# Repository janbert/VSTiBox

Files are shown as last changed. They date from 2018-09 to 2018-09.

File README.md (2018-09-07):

# VSTiBox
VSTiBox is a dedicated VST host synth for live performance. It is a Windows based machine that contains all components to run VST software synths that are controlled by an external midi keyboard. Key components are:
- Micro-ATX with Intel i5 running Windows 7
- Custom wooden/acrylic lasercut case
- Custon VST host software written in C#
- Custom audio mixer with multiple I/O and headphone out
- Custom linear audio PSU 230Vac in, +/-10Vdc out
- Custom interface boards with 8x 24PPR encoders and 8x RGB silicon pad buttons 

See my project page at hackaday for more info: https://hackaday.io/project/160858-vstibox

# Build instructions
For all hardware v1.0 is added including the GERBER files that I used for ordering the pcb's. Both the mixer and the control interface contain bugs and need some rewiring. I have corrected the schematics in v1.1, but did not take the time to finish the pcb's. I do recommend finalizing the v1.1 boards if you want to build your own, instead of re-ordering my v1.0 versions. 

# Libraries
This project uses a number of libraries. 
- BlueWave.Interop.Asio	https://www.codeproject.com/Articles/24536/Low-Latency-Audio-using-ASIO-Drivers-in-NET?msg=4526889
- VST.NET               https://github.com/obiwanjacobi/vst.net
- midi-dot-net	        https://code.google.com/archive/p/midi-dot-net/
- DirectMidi.net        http://directmidinet.sourceforge.net/
- NAudio	              https://github.com/naudio/NAudio
- OpenHardwareMonitor	  https://openhardwaremonitor.org
- PDFViewer	            https://www.codeproject.com/Articles/37458/PDF-Viewer-Control-Without-Acrobat-Reader-Installe

# License
This project is distributed under the the GNU general public license v3.

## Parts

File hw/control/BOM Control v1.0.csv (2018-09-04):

Qty | Value | Device | Package | Parts | Description
2 |  | M04LOCK | 1X04_LOCK | JP2, JP6 | Header 4
1 |  | PINHD-1X3 | 1X03 | JP1 | PIN HEADER
12 | 100 | R-EU_R0603 | R0603 | R4, R7, R8, R10, R12, R15, R16, R17, R18, R19, R22, R23 | RESISTOR, European symbol
3 | 100nF | C-EUC0603 | C0603 | C3, C14, C15 | CAPACITOR, European symbol
1 | 100nF | CAP0603-CAP | 0603-CAP | C2 | Capacitor
2 | 100uF 6.3V | CPOL-EUSMCB | SMC_B | C1, C4 | POLARIZED CAPACITOR, European symbol
1 | 10MHz | CRYSTALSMD | HC49UP | Y1 | Various standard crystals. Proven footprints. Spark Fun Electronics SKU : COM-00534
5 | 10k | R-EU_R0603 | R0603 | R3, R13, R14, R20, R21 | RESISTOR, European symbol
2 | 10k lin | TRIM_EU-3223W | 3223W | R28, R29 | POTENTIOMETER
4 | 150 | R-EU_R0603 | R0603 | R1, R6, R26, R33 | RESISTOR, European symbol
2 | 20pF | C-EUC0603 | C0603 | C5, C6 | CAPACITOR, European symbol
4 | 348 | R-EU_R0603 | R0603 | R5, R25, R32, R35 | RESISTOR, European symbol
2 | 4k7 | R-EU_R0603 | R0603 | R30, R31 | RESISTOR, European symbol
4 | 620 | R-EU_R0603 | R0603 | R2, R24, R27, R34 | RESISTOR, European symbol
2 | BUTTONPAD-2X1 | BUTTONPAD-2X1 | BUTTONPAD-2X1 | U$1, U$3
1 | ENC1 | M04PTH | 1X04 | JP4 | Header 4
1 | ENC2 | M04PTH | 1X04 | JP5 | Header 4
1 | ENC3 | M04PTH | 1X04 | JP7 | Header 4
1 | ENC4 | M04PTH | 1X04 | JP8 | Header 4
1 | JTAG_10WAY | JTAG_10WAY | JTAG_10WAY_1.27MM | X1
1 | LM1117_3V3 | LM1117_3V3 | SOT223 | U$26
1 | LPC1113/14-LQFP48 | LPC1113/14-LQFP48 | LQFP48 | U$4 | NXP Semiconductors
1 | M02PTH | M02PTH | 1X02 | JP9 | Standard 2-pin 0.1 header. Use with"
1 | OPA177S | OPA177S | SO08 | IC1 | Precision Operational Amplifier
12 | PMV31XN | MOSFET-NREFLOW | SOT23 | Q3, Q4, Q5, Q6, Q7, Q8, Q9, Q10, Q11, Q12, Q13, Q14 | N-Channel Mosfet
1 | SE95DP | SE95DP | TSSOP8-SOT505-1 | U2

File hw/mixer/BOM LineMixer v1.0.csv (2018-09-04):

Qty | Value | Device | Package | Parts | Description
4 |  | NSJ12HF-1 | NSJ12HF-1 | U$1, U$2, U$3, U$6 | Stereo dual jack, full threaded nose
1 | 1.62M | R-EU_R0603 | R0603 | R49 | RESISTOR, European symbol
8 | 100R | R-EU_0207/7 | 0207/7 | R29, R30, R31, R32, R61, R62, R63, R64 | RESISTOR, European symbol
8 | 100k | R-EU_0207/7 | 0207/7 | R1, R2, R3, R4, R10, R27, R45, R46 | RESISTOR, European symbol
1 | 100k\ | R-EU_0207/7 | 0207/7 | R11 | RESISTOR, European symbol
20 | 100n | C-EUC0603 | C0603 | C1, C2, C3, C4, C5, C6, C20, C21, C22, C23, C24, C25, C39, C41, C44, C46, C47, C48, C49, C50 | CAPACITOR, European symbol
2 | 100nF | C-EUC0603 | C0603 | C28, C29 | CAPACITOR, European symbol
6 | 10k | R-EU_0207/7 | 0207/7 | R13, R14, R18, R19, R28, R35 | RESISTOR, European symbol
3 | 10k log | 3RP/1610G | 3RP/1610G | R9, R22, R44 | 16mm Potentiometer two level
2 | 10nF | C-EUC0603 | C0603 | C33, C34 | CAPACITOR, European symbol
4 | 1M | R-EU_0207/7 | 0207/7 | R51, R52, R56, R58 | RESISTOR, European symbol
6 | 1k | R-EU_0207/7 | 0207/7 | R53, R54, R55, R57, R59, R60 | RESISTOR, European symbol
2 | 1uF | C-EUC0603 | C0603 | C30, C38 | CAPACITOR, European symbol
1 | 1uf | C-EUC0603 | C0603 | C37 | CAPACITOR, European symbol
1 | 20k8 | R-EU_R0603 | R0603 | R47 | RESISTOR, European symbol
1 | 215k | R-EU_R0603 | R0603 | R50 | RESISTOR, European symbol
7 | 220p | C-EUC0603K | C0603K | C12, C13, C14, C17, C18, C31, C32 | CAPACITOR, European symbol
2 | 220uF | CPOL-EUD/7343-31R | D/7343-31R | C35, C36 | POLARIZED CAPACITOR, European symbol
22 | 2k49 | R-EU_0207/7 | 0207/7 | R5, R6, R7, R8, R12, R17, R20, R21, R23, R24, R25, R26, R33, R34, R36, R37, R38, R39, R40, R41, R42, R43 | RESISTOR, European symbol
1 | 2k87 | R-EU_R0603 | R0603 | R48 | RESISTOR, European symbol
5 | 4.7uF | C15/7 | C15B7 | C7, C8, C9, C10, C11 | CAPACITOR
3 | 47p | C-EUC0603K | C0603K | C15, C16, C19 | CAPACITOR, European symbol
2 | 47uF | CPOL-EUD/7343-31R | D/7343-31R | C26, C27 | POLARIZED CAPACITOR, European symbol
2 | 4k99 | R-EU_0207/7 | 0207/7 | R15, R16 | RESISTOR, European symbol
4 | 4u7 16V | C-EUC1206 | C1206 | C40, C42, C43, C45 | CAPACITOR, European symbol
4 | DRV134SO-8 | DRV134SO-8 | SO-8 | U1, U2, U3, U4
1 | INA2134-EP | INA2134U | SO14 | IC1 | Audio Differential Line Receivers
2 | LM4558D | LM4558D | SO08 | IC2, IC5 | OP AMP
1 | LM4562 | LM4558D | SO08 | IC4 | OP AMP
2 | LME49600 | LME49600 | TS5B | IC7, IC8 | High Performance, High Fidelity, High Current Audio Buffer
2 | LME49740 | TL074D | SO14 | IC3, IC6 | OP AMP
3 | MOUNT-HOLE3.2 | MOUNT-HOLE3.2 | 3,2 | H1, H3, H4 | MOUNTING HOLE with drill center marker
15 | PAD1.5MM | PAD1.5MM | PAD_1.5MM | U$7, U$8, U$10, U$11, U$12, U$13, U$14, U$15, U$16, U$17, U$18, U$19, U$20, U$21, U$22
5 | SOLDERLINK | SOLDERLINK | SOLDERLINK | S1, S2, S3, S4, S5
1 | TPS7A3301KC | TPS7A3301KC | TO220-7 | U$4 | Ultralow-Noise Negative Voltage Regulator v3
1 | TPS7A4501 | TPS7A4501 | SOT223-5 | U$5 | LOW-NOISE FAST-TRANSIENT-RESPONSE 1.5-A LOW-DROPOUT VOLTAGE

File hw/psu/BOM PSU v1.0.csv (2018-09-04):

Qty | Value | Device | Package | Parts | Description
7 | Schottky MBR0520L | DIODE-DO214AC | DO214AC | D1, D2, D3, D4, D5, D6, D7, D8 | DIODE
2 | 1 | R-EU_R0603 | R0603 | R2, R3 | RESISTOR, European symbol
4 | 10uF 25V 0805 | C-EUC1206 | C1206 | C11, C12, C27, C28 | CAPACITOR, European symbol
1 | 1MEG | R-EU_0309/12 | 0309/12 | R6 | RESISTOR, European symbol
2 | 1nF | C-EUC0603 | C0603 | C31, C32 | CAPACITOR, European symbol
2 | 1uF | C-EUC0603 | C0603 | C17, C18 | CAPACITOR, European symbol
2 | 3300uF 25V | CPOL-EUE7.5-16 | E7,5-16 | C23, C24 | POLARIZED CAPACITOR, European symbol
2 | 4700uF 16V | CPOL-EUE7.5-16 | E7,5-16 | C9, C10 | POLARIZED CAPACITOR, European symbol
2 | 47uF 16V 1210 | C-EUC1210 | C1210 | C25, C26 | CAPACITOR, European symbol
3 | S10K300 | S10K300 | S10K300 | R1, R4, R5 | VARISTOR
1 | Talema 70022K 5VA 2x12Vac | TALEMA_70000 | TALEMA_70000 | L2 | TRANSFORMER
1 | Hammond 1591XXSSFLBK |  |  |  | ABS Enclosure, IP54, Flanged, 112.52 x 84.62 x 41.25mm
1 | FIX-GR-1 |  |  |  | Rubber grommet
2 | FIX-GR-30 |  |  |  | Rubber grommet
2 | TPS7A4700 | TPS7A4700 | VQFN20 | U1, U2 | Ultralow-noise LDO
1 | TAKAMISAWA NA12W-K
1 | SU9V-R01180 | SU9V-R01180 | SU9V-R01180 | L1 | Common mode choke
2 | KF301-3P | MKDSN1,5/3-5,08 | MKDSN1,5/3-5,08 | X1, X2 | MKDSN 1,5/ 3-5,08 Printklemme
1 | KF301-2P
1 | 47nF 600V 473J | C-EU102-064X133 | C102-064X133 | C19 | CAPACITOR, European symbol
2 | 4.7nF Class Y VY1472M61Y5UC63V0 | C-EU102-054X133 | C102-054X133 | C21, C22 | CAPACITOR, European symbol
1 | 100nF 400V 104J | C-EU150-064X183 | C150-064X183 | C20 | CAPACITOR, European symbol
1 | FUSEX20MM | FUSEX20MM | FUSE_5MM | F1
14 | 100nF : type MLCC?! | C-EUC0603 | C0603 | C1, C2, C3, C4, C5, C6, C7, C8, C13, C14, C15, C16, C29, C30 | CAPACITOR, European symbol

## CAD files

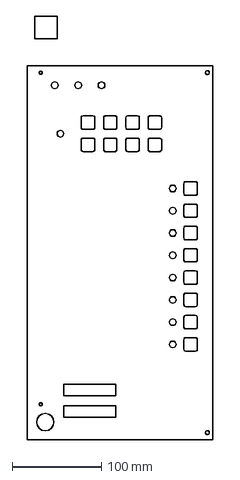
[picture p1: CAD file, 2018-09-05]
cad/lasercut/1_16 inch/Topplate clear.DXF
207.9 x 475.5 mm

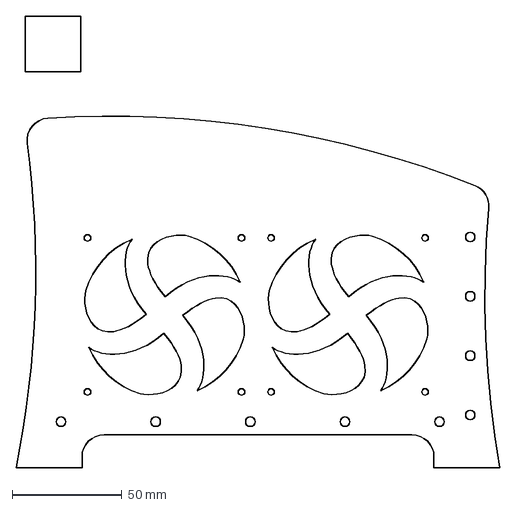
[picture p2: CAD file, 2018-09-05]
cad/lasercut/1_2 inch/Sideplate fanholes clear 1_2inch.DXF
220.0 x 205.4 mm

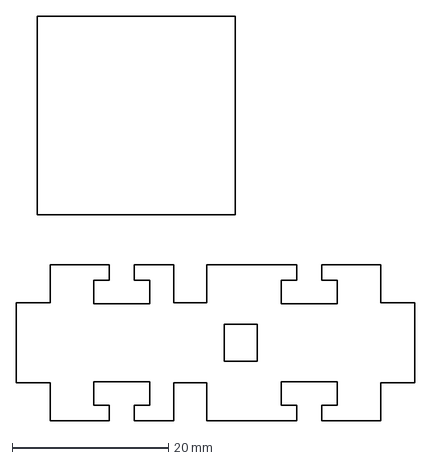
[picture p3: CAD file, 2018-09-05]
cad/lasercut/3_16 inch/Modwheel side.DXF
51.0 x 51.8 mm

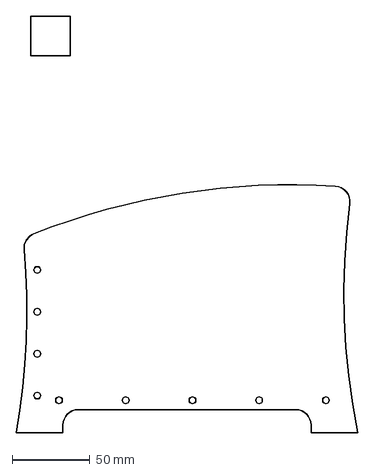
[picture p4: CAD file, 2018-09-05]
cad/lasercut/1_2 inch/Sideplate no fanholes clear 1_2inch.DXF
220.0 x 268.5 mm

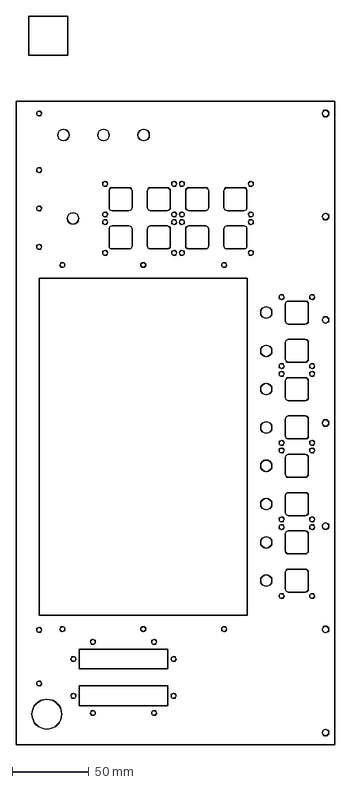
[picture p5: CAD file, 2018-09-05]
cad/lasercut/3_16 inch/Topplate black.DXF
207.9 x 475.5 mm

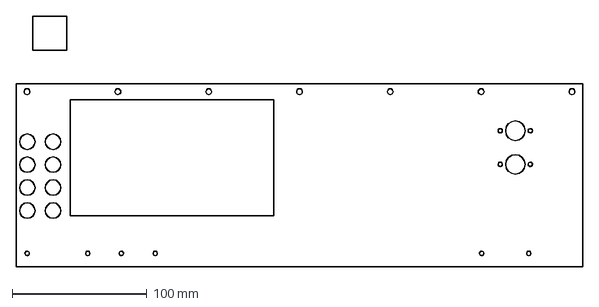
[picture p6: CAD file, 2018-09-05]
cad/lasercut/3_16 inch/Back plate.DXF
420.0 x 186.1 mm

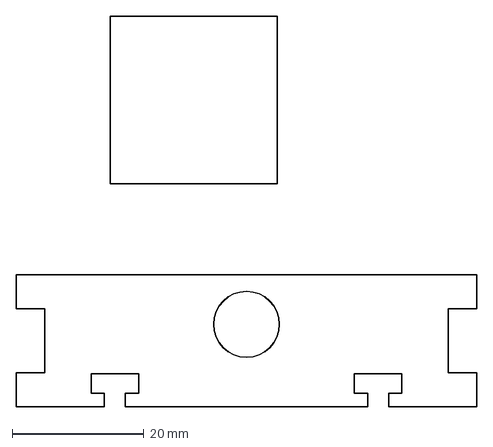
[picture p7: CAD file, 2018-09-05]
cad/lasercut/3_16 inch/Modwheel base.DXF
70.0 x 59.3 mm

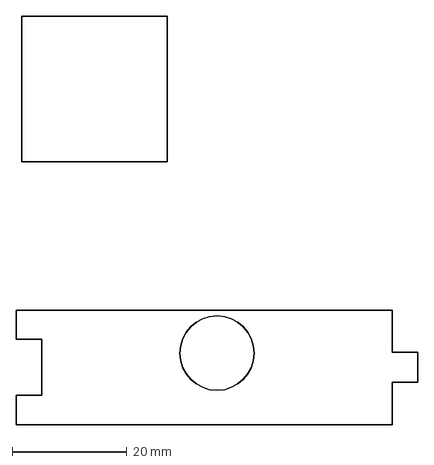
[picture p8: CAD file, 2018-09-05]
cad/lasercut/3_16 inch/Modwheel mid.DXF
70.0 x 71.3 mm

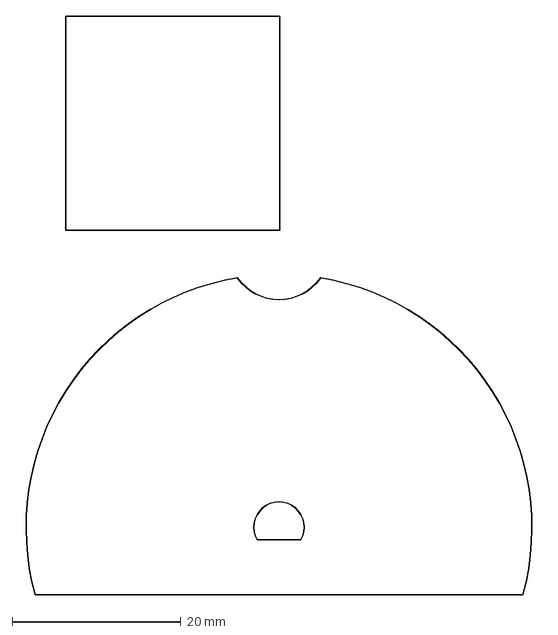
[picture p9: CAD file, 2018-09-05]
cad/lasercut/3_16 inch/Modwheel.DXF
62.4 x 68.6 mm

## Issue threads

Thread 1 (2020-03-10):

Great work!

beevabeeva, 2020-03-10:
Hi there Jan!

I am so glad I found your project.
I've wanted to create a similar thing for years.
Your software setup looks great!
I'd want to add a patch browser (with giant text so I can see the patch name while playing live) - Similar to something like Apples' Mainstage.

I am not going for something as elaborate in terms of the custom controller hardware (which is very cool!).

This is my plan:

Casio CDP 100
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

# +
Korg Nano Kontrol
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

# +

Mini pc with serial port for midi in (creating a midi to serial connector will be faster than any midi to usb converter unfortunately. For newer keyboards with usb to usb, this is not an issue).
i5 or i7 with as much RAM possible. +- 128 GB SSD.
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

# +

10 or 13 inch touch screen monitor.
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

I want to build a road case for the keyboard and have everything fit into that.
Something like this:
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

Finally, I'll have a plug bar in the case, so that I can leave everything plugged in and connected. I'll only need to plug one thing in and be ready to play. Like the good old days.

Thanks for sharing your work. It will definitely help me.

janbert, 2020-03-10:
Hi, nice to see that my project inspired you! Nice to see your plans too. Good luck building it! I'm curious to see the result so please send me a pic once you have finished it.
Regards, Jan Bert

________________________________
Van: beevabeeva <notifications@github.com>
Verzonden: dinsdag 10 maart 2020 03:43
Aan: janbert/VSTiBox <VSTiBox@noreply.github.com>
CC: Subscribed <subscribed@noreply.github.com>
Onderwerp: [janbert/VSTiBox] Great work! (#1)

Hi there Jan!

I am so glad I found your project.
I've wanted to create a similar thing for years.
Your software setup looks great!
I'd want to add a patch browser (with giant text so I can see the patch name while playing live) - Similar to something like Apples' Mainstage.

I am not going for something as elaborate in terms of the custom controller hardware (which is very cool!).

This is my plan:

Casio CDP 100
[Casio CDP100]<https://user-images.githubusercontent.com/19332617/76275354-baab8300-628b-11ea-8126-89058b77c8d9.png>

+

Korg Nano Kontrol
[image]<https://user-images.githubusercontent.com/19332617/76275462-0f4efe00-628c-11ea-92bd-5e58f79c2b51.png>

+

Mini pc with serial port for midi in (creating a midi to serial connector will be faster than any midi to usb converter unfortunately. For newer keyboards with usb to usb, this is not an issue).
i5 or i7 with as much RAM possible. +- 128 GB SSD.
[image]<https://user-images.githubusercontent.com/19332617/76275889-1fb3a880-628d-11ea-8df0-2ead58ff0844.png>

+

10 or 13 inch touch screen monitor.
[image]<https://user-images.githubusercontent.com/19332617/76276186-de6fc880-628d-11ea-93c6-8c37bda4e486.png>

I want to build a road case for the keyboard and have everything fit into that.
Something like this:
[image]<https://user-images.githubusercontent.com/19332617/76276365-4a523100-628e-11ea-9f9d-8cefc426486c.png>

Finally, I'll have a plug bar in the case, so that I can leave everything plugged in and connected. I'll only need to plug one thing in and be ready to play. Like the good old days.

Thanks for sharing your work. It will definitely help me.

—
You are receiving this because you are subscribed to this thread.
Reply to this email directly, view it on GitHub<https://github.com/janbert/VSTiBox/issues/1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>, or unsubscribe<https://github.com/notifications/unsubscribe-auth/AB74PQ2VKLS2KZMVR3TWKJLRGWZNLANCNFSM4LEWGVQA>.

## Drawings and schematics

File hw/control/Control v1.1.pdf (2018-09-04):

POWER | TEMPERATURE SENSOR

# SWD

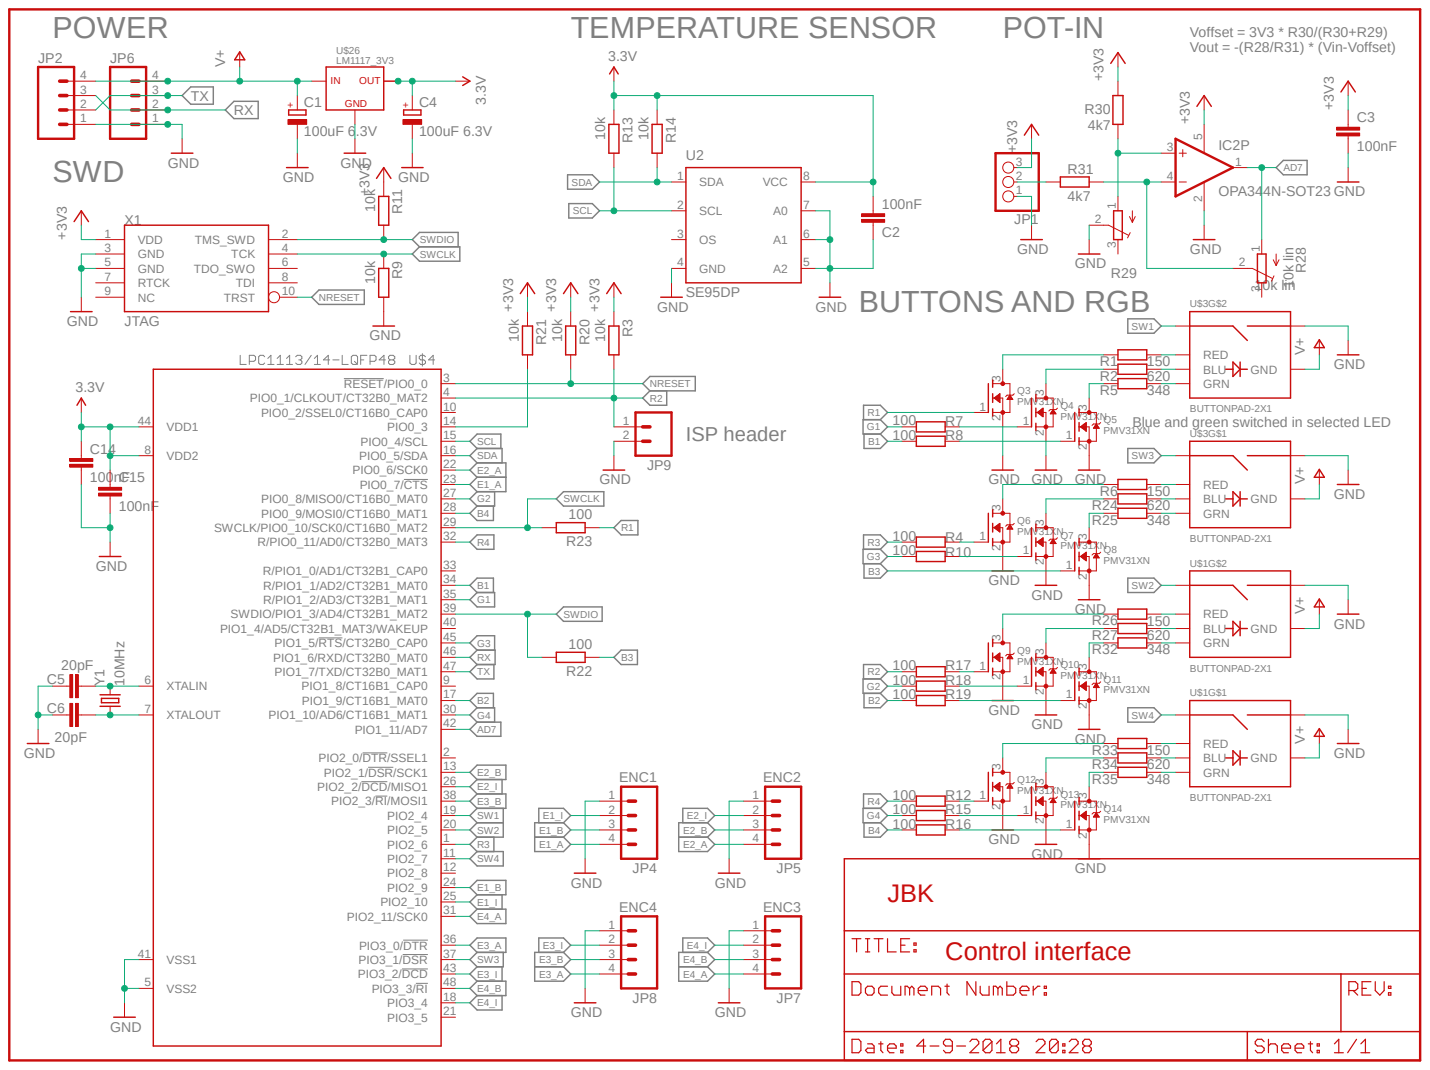
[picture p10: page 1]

Blue and green switched in selected LED

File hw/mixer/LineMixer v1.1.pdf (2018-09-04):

2k49 | 100k
GND | 4u7 16V 4u7 16V | 4u7 16V ⁴u7 16V

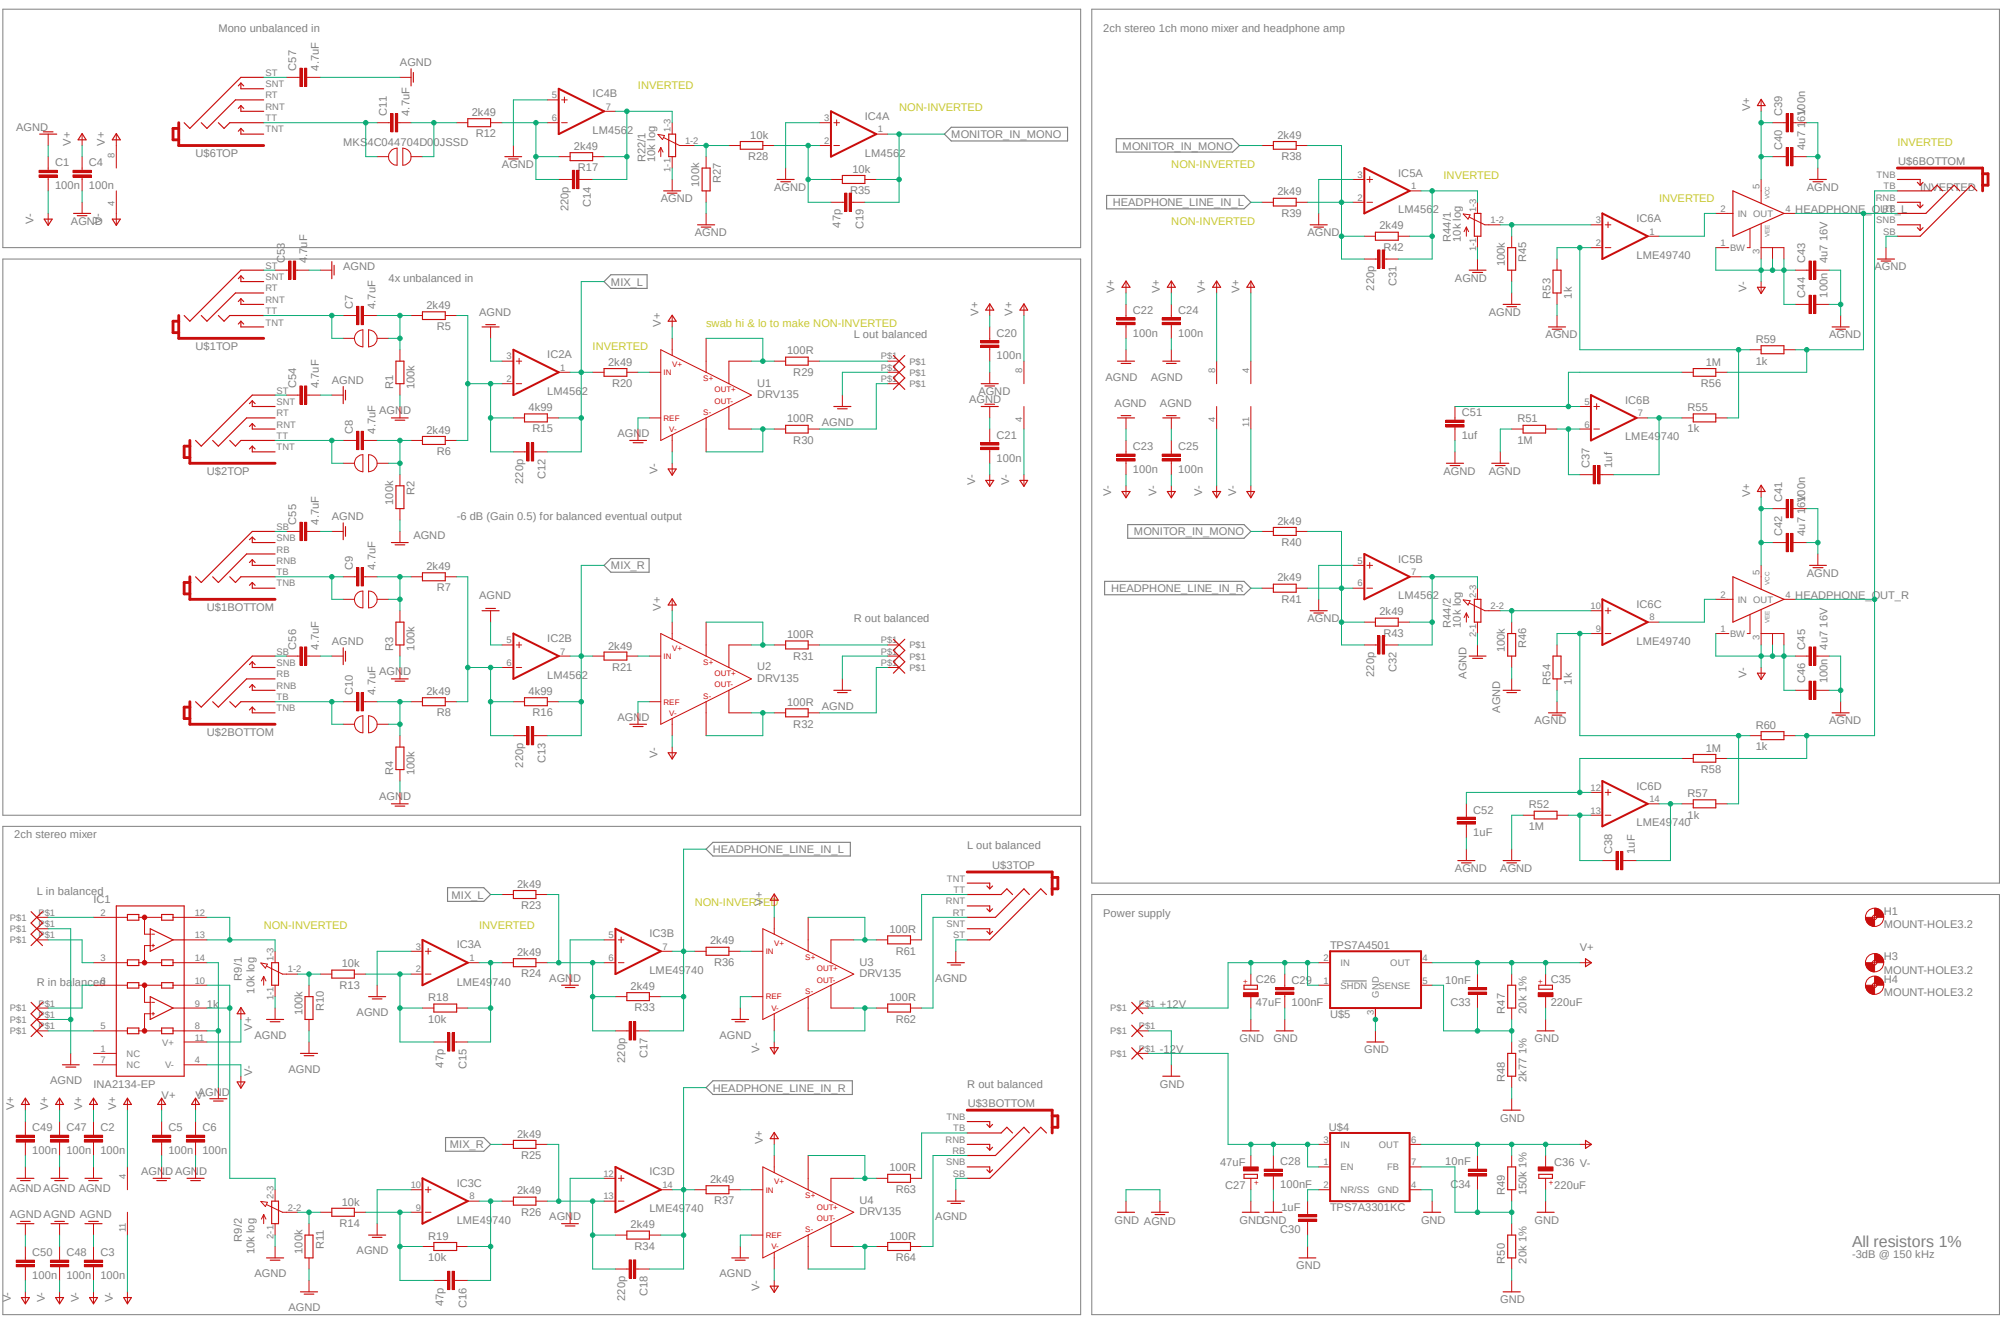
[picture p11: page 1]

2ch stereo 1ch mono mixer and headphone amp

C33 C¹¹ C⁷ C⁸ C⁹ C¹⁰

swab hi & lo to make NON-INVERTED

-6 dB (Gain 0.5) for balanced eventual output

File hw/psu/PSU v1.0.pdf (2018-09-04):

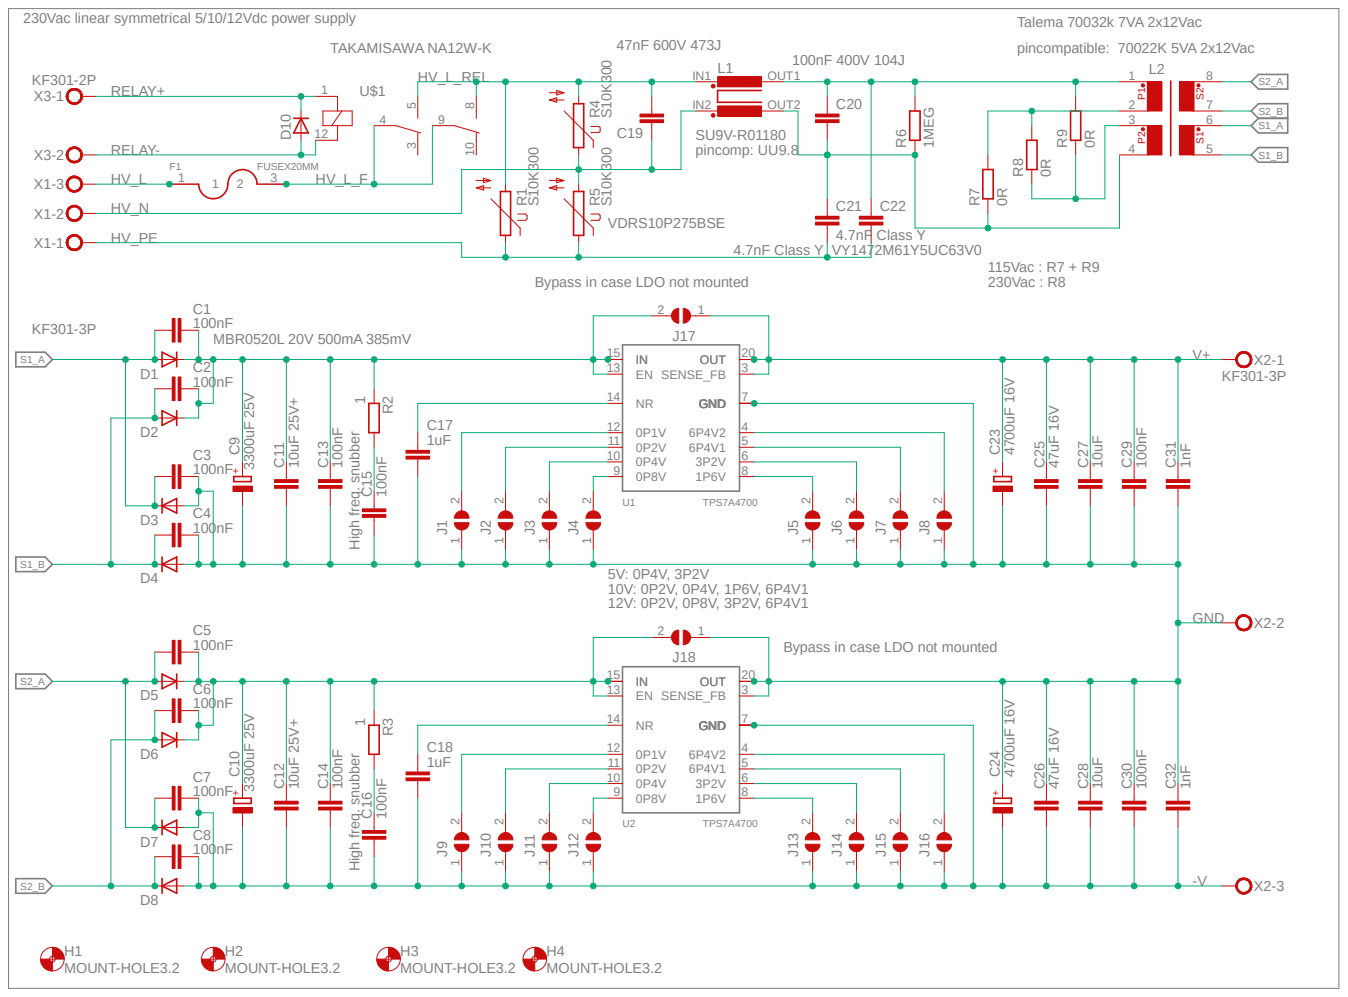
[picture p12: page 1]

230Vac linear symmetrical 5/10/12Vdc power supply

Bypass in case LDO not mounted

Bypass in case LDO not mounted High freq. snubber High freq. snubber

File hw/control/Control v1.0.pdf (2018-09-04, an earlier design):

POWER | TEMPERATURE SENSOR

# SWD

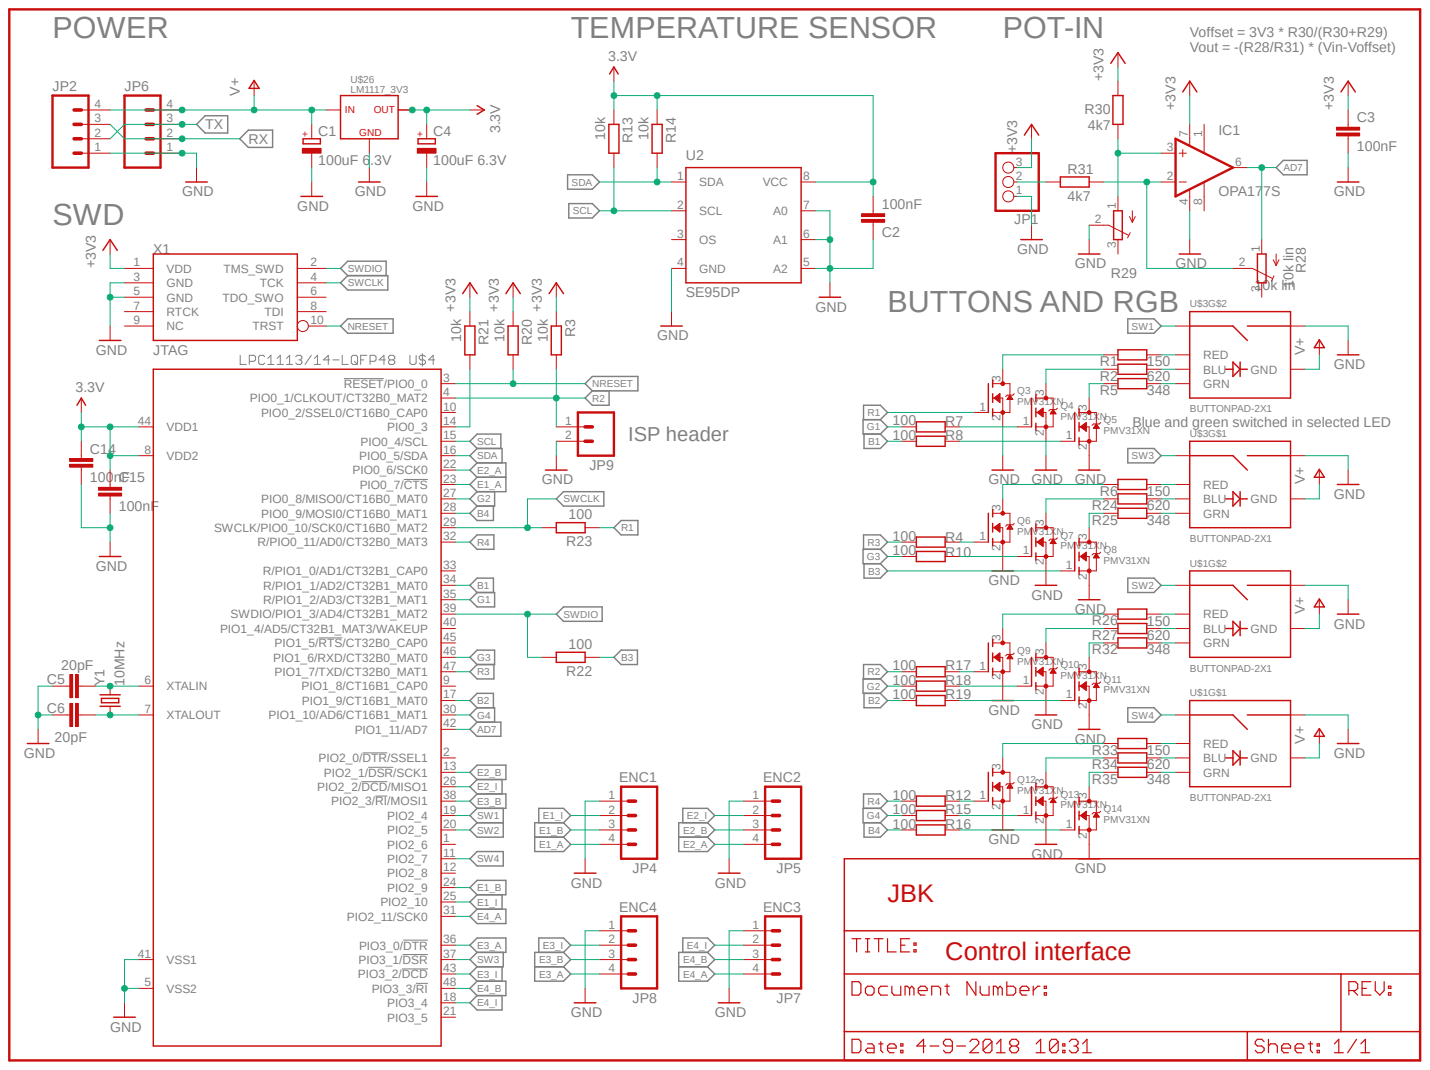
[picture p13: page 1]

Blue and green switched in selected LED

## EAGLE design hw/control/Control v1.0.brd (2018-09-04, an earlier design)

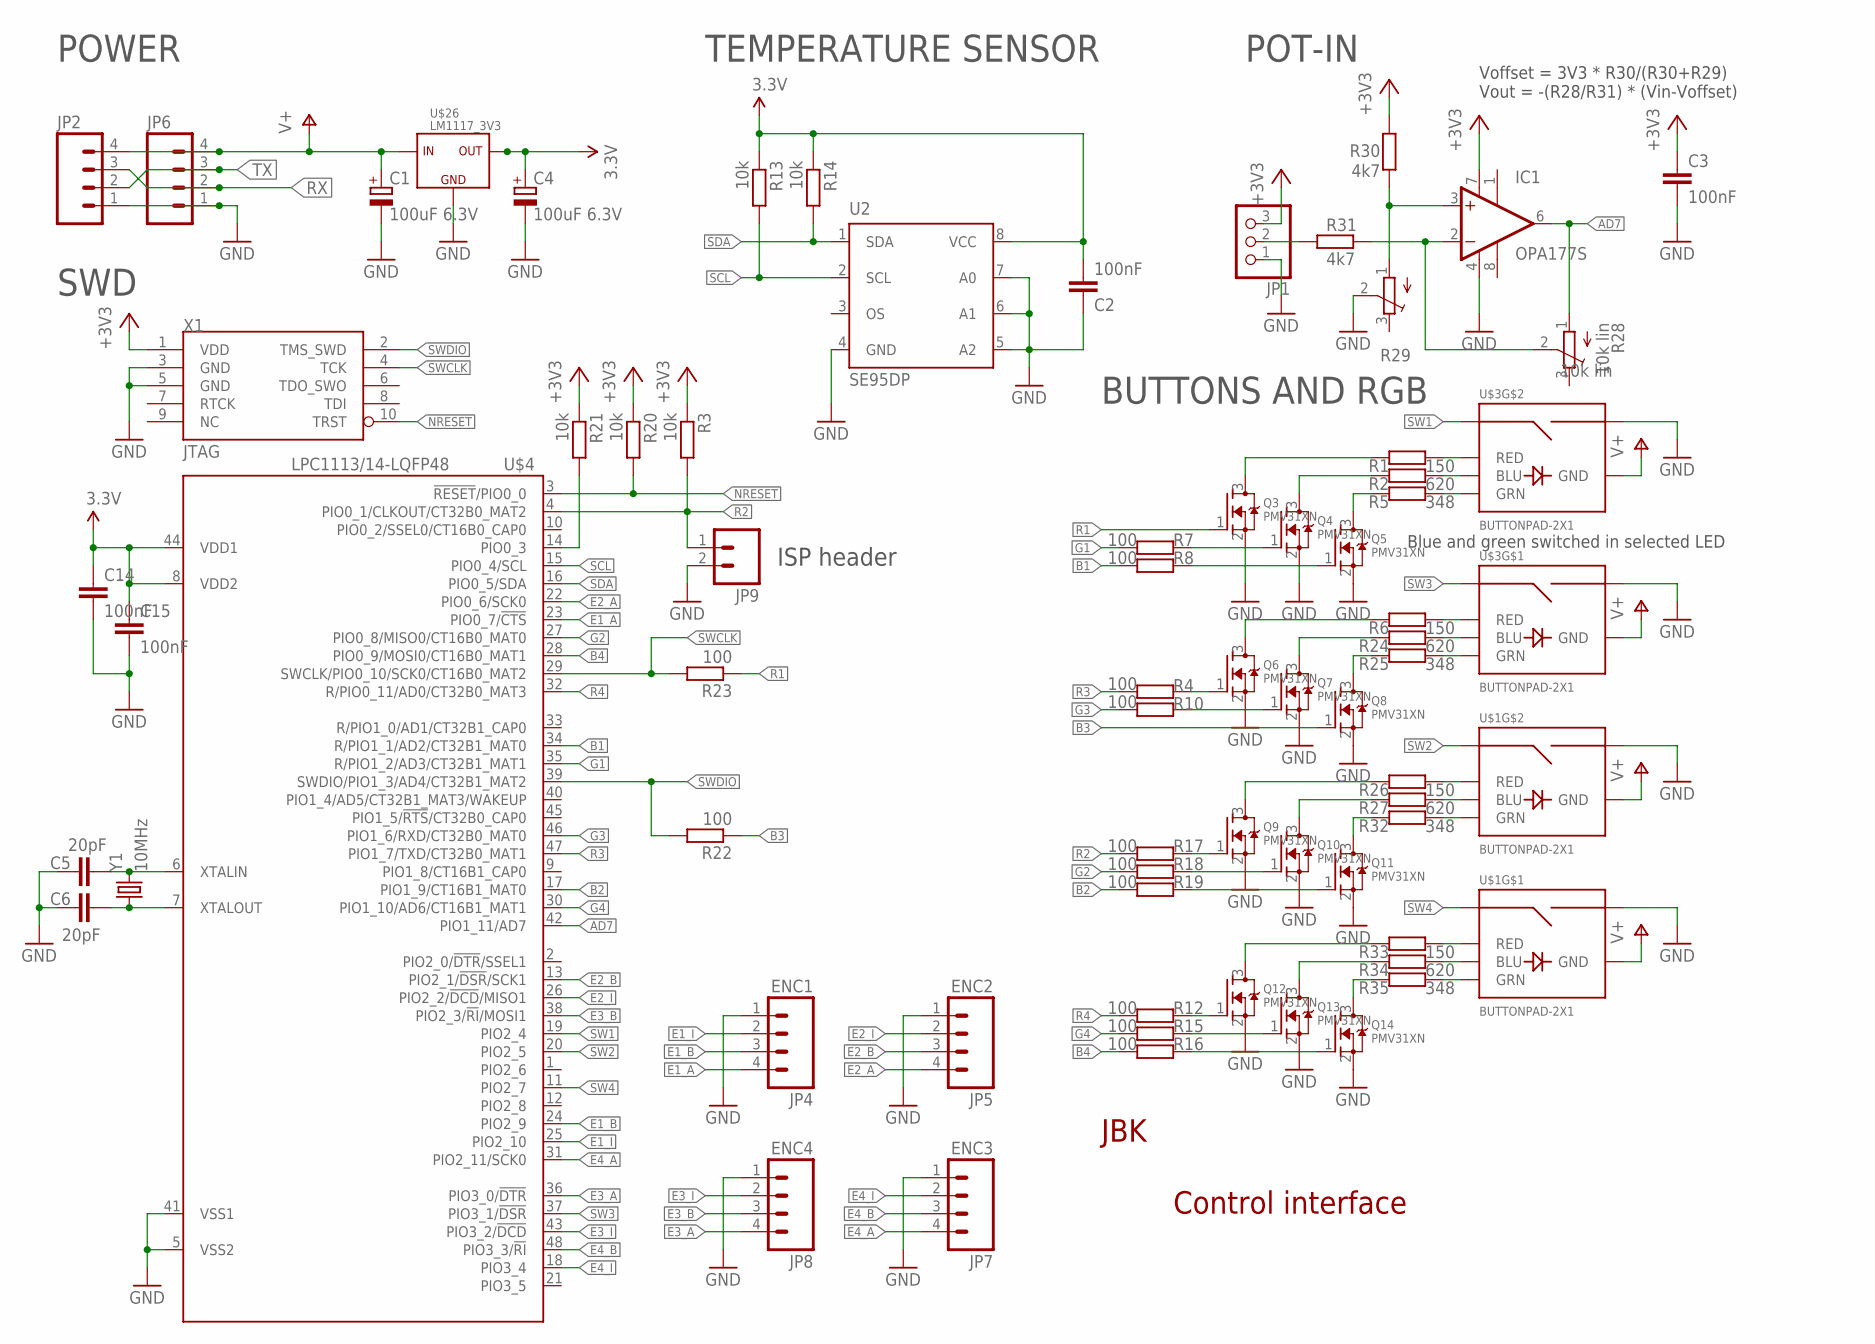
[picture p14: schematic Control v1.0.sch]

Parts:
C1, C4: 100uF 6.3V; SMC_B
C2: 100nF; 0603-CAP
C3, C14, C15: 100nF; C0603
C5, C6: 20pF; C0603
IC1: OPA177S; SO08
JP1: PINHD-1X3; 1X03
JP2, JP6: M04LOCK; 1X04_LOCK
JP4: ENC1; 1X04
JP5: ENC2; 1X04
JP7: ENC3; 1X04
JP8: ENC4; 1X04
JP9: M02PTH; 1X02
Q3, Q4, Q5, Q6, Q7, Q8, Q9, Q10, Q11, Q12, Q13, Q14: PMV31XN; SOT23
R1, R6, R26, R33: 150; R0603
R2, R24, R27, R34: 620; R0603
R3, R13, R14, R20, R21: 10k; R0603
R4, R7, R8, R10, R12, R15, R16, R17, R18, R19, R22, R23: 100; R0603
R5, R25, R32, R35: 348; R0603
R28, R29: 10k lin; 3223W
R30, R31: 4k7; R0603
U2: SE95DP; TSSOP8-SOT505-1
U$1, U$3: BUTTONPAD-2X1
U$4: LPC1113/14-LQFP48; LQFP48
U$26: LM1117_3V3; SOT223
X1: JTAG_10WAY; JTAG_10WAY_1.27MM
Y1: 10MHz; HC49UP

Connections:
+3V3: C2.2, C3.1, C4.+, C14.1, C15.1, IC1.7 (V+), JP1.3, R3.1, R13.1, R14.1, R20.1, R21.1, R30.2, U2.8 (VCC), U$4.8 (VDD2), U$4.44 (VDD1), U$26.2 (OUT), U$26.4 (OUT), X1.1 (VDD)
AD7: IC1.6 (OUT), R28.1 (A), U$4.42 (PIO1_11/AD7)
B1: R8.2, U$4.34 (R/PIO1_1/AD2/CT32B1_MAT0)
B2: R19.2, U$4.17 (PIO1_9/CT16B1_MAT0)
B3: Q8.1 (G), R22.1
B4: R16.2, U$4.28 (PIO0_9/MOSI0/CT16B0_MAT1)
E1_A: JP4.4, U$4.23 (PIO0_7/!CTS!)
E1_B: JP4.3, U$4.24 (PIO2_9)
E1_I: JP4.2, U$4.25 (PIO2_10)
E2_A: JP5.4, U$4.22 (PIO0_6/SCK0)
E2_B: JP5.3, U$4.13 (PIO2_1/!DSR!/SCK1)
E2_I: JP5.2, U$4.26 (PIO2_2/!DCD!/MISO1)
E3_A: JP8.4, U$4.36 (PIO3_0/!DTR!)
E3_B: JP8.3, U$4.38 (PIO2_3/!RI!/MOSI1)
E3_I: JP8.2, U$4.43 (PIO3_2/!DCD!)
E4_A: JP7.4, U$4.31 (PIO2_11/SCK0)
E4_B: JP7.3, U$4.48 (PIO3_3/!RI!)
E4_I: JP7.2, U$4.18 (PIO3_4)
G1: R7.2, U$4.35 (R/PIO1_2/AD3/CT32B1_MAT1)
G2: R18.2, U$4.27 (PIO0_8/MISO0/CT16B0_MAT0)
G3: R10.2, U$4.46 (PIO1_6/RXD/CT32B0_MAT0)
G4: R15.2, U$4.30 (PIO1_10/AD6/CT16B1_MAT1)
GND: C1.-, C2.1, C3.2, C4.-, C5.1, C6.1, C14.2, C15.2, IC1.4 (V-), JP1.1, JP2.1, JP4.1, JP5.1, JP6.1, JP7.1, JP8.1, JP9.2, Q3.2 (S), Q4.2 (S), Q5.2 (S), Q6.2 (S), Q7.2 (S), Q8.2 (S), Q9.2 (S), Q10.2 (S), Q11.2 (S), Q12.2 (S), Q13.2 (S), Q14.2 (S), R29.2 (S), U2.4 (GND), U2.5 (A2), U2.6 (A1), U2.7 (A0), U$1.SW0-1 (SIG2), U$1.SW1-1 (SIG2), U$3.SW0-1 (SIG2), U$3.SW1-1 (SIG2), U$4.5 (VSS2), U$4.41 (VSS1), U$26.1, X1.3 (GND), X1.5 (GND)
unnamed: Q6.3 (D), R6.1
unnamed: Q7.3 (D), R24.1
unnamed: Q8.3 (D), R25.1
unnamed: R21.2, U$4.14 (PIO0_3)
unnamed: Q6.1 (G), R4.1
unnamed: Q4.3 (D), R2.1
unnamed: Q5.3 (D), R5.1
unnamed: IC1.2 (-IN), R28.2 (S), R31.2
unnamed: IC1.3 (+IN), R29.1 (A), R30.1
unnamed: Q7.1 (G), R10.1
unnamed: Q9.1 (G), R17.1
unnamed: Q9.3 (D), R26.1
unnamed: Q10.3 (D), R27.1
unnamed: Q3.3 (D), R1.1
unnamed: Q11.3 (D), R32.1
unnamed: Q4.1 (G), R7.1
unnamed: Q5.1 (G), R8.1
unnamed: Q10.1 (G), R18.1
unnamed: Q11.1 (G), R19.1
unnamed: JP1.2, R31.1
unnamed: C5.2, U$4.6 (XTALIN), Y1.2
unnamed: C6.2, U$4.7 (XTALOUT), Y1.1
unnamed: Q12.1 (G), R12.1
unnamed: Q12.3 (D), R33.1
unnamed: Q13.3 (D), R34.1
unnamed: Q14.3 (D), R35.1
unnamed: Q13.1 (G), R15.1
unnamed: Q14.1 (G), R16.1
unnamed: R1.2, U$3.RED1 (RED)
unnamed: R2.2, U$3.BLU1 (BLU)
unnamed: R5.2, U$3.GRN1 (GRN)
unnamed: R6.2, U$3.RED0 (RED)
unnamed: R24.2, U$3.BLU0 (BLU)
unnamed: R25.2, U$3.GRN0 (GRN)
unnamed: R26.2, U$1.RED1 (RED)
unnamed: R27.2, U$1.BLU1 (BLU)
unnamed: R32.2, U$1.GRN1 (GRN)
unnamed: R33.2, U$1.RED0 (RED)
unnamed: R34.2, U$1.BLU0 (BLU)
unnamed: R35.2, U$1.GRN0 (GRN)
NRESET: R20.2, U$4.3 (!RESET!/PIO0_0), X1.10 (TRST)
R1: Q3.1 (G), R23.1
R2: JP9.1, R3.2, R17.2, U$4.4 (PIO0_1/CLKOUT/CT32B0_MAT2)
R3: R4.2, U$4.47 (PIO1_7/TXD/CT32B0_MAT1)
R4: R12.2, U$4.32 (R/PIO0_11/AD0/CT32B0_MAT3)
RX: JP2.3, JP6.2
SCL: R13.2, U2.2 (SCL), U$4.15 (PIO0_4/SCL)
SDA: R14.2, U2.1 (SDA), U$4.16 (PIO0_5/SDA)
SW1: U$3.SW1-0 (SIG1), U$4.19 (PIO2_4)
SW2: U$1.SW1-0 (SIG1), U$4.20 (PIO2_5)
SW3: U$3.SW0-0 (SIG1), U$4.37 (PIO3_1/!DSR!)
SW4: U$1.SW0-0 (SIG1), U$4.11 (PIO2_7)
SWCLK: R23.2, U$4.29 (SWCLK/PIO0_10/SCK0/CT16B0_MAT2), X1.4 (TCK)
SWDIO: R22.2, U$4.39 (SWDIO/PIO1_3/AD4/CT32B1_MAT2), X1.2 (TMS_SWD)
TX: JP2.2, JP6.3
V+: C1.+, JP2.4, JP6.4, U$1.GND0 (GND), U$1.GND1 (GND), U$3.GND0 (GND), U$3.GND1 (GND), U$26.3

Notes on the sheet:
Control interface
JBK
TEMPERATURE SENSOR
POWER
SWD
ISP header
Voffset = 3V3 * R30/(R30+R29) Vout = -(R28/R31) * (Vin-Voffset)
POT-IN
BUTTONS AND RGB
Blue and green switched in selected LED

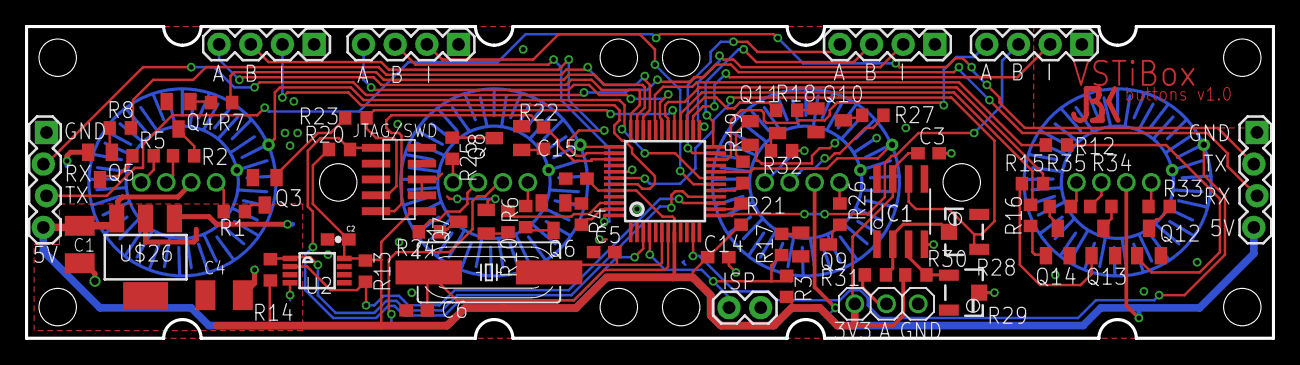
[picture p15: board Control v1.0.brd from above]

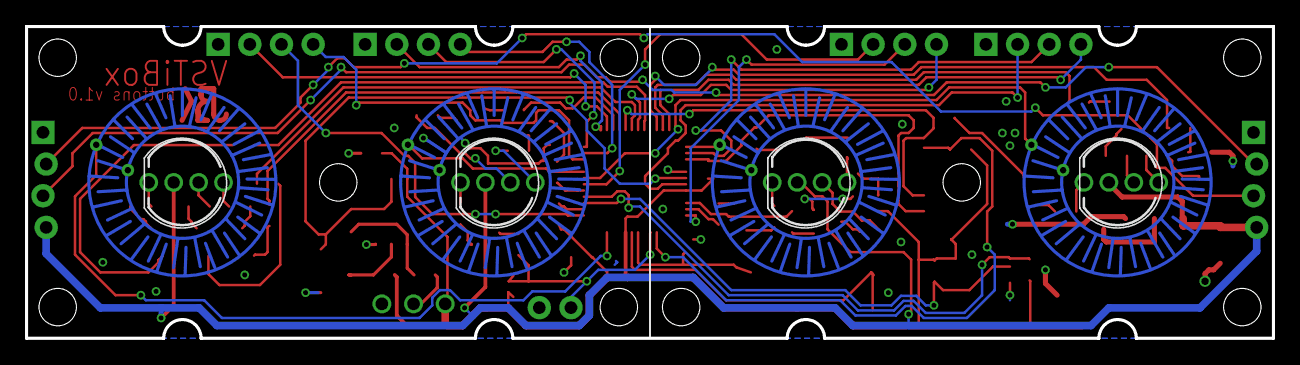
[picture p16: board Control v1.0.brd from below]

Board: 2 copper layers, 100.0 x 25.0 mm, 70 parts (2 on the bottom side), 79 nets.

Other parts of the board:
U$9: JBK_LOGO_SMALL_COPPER

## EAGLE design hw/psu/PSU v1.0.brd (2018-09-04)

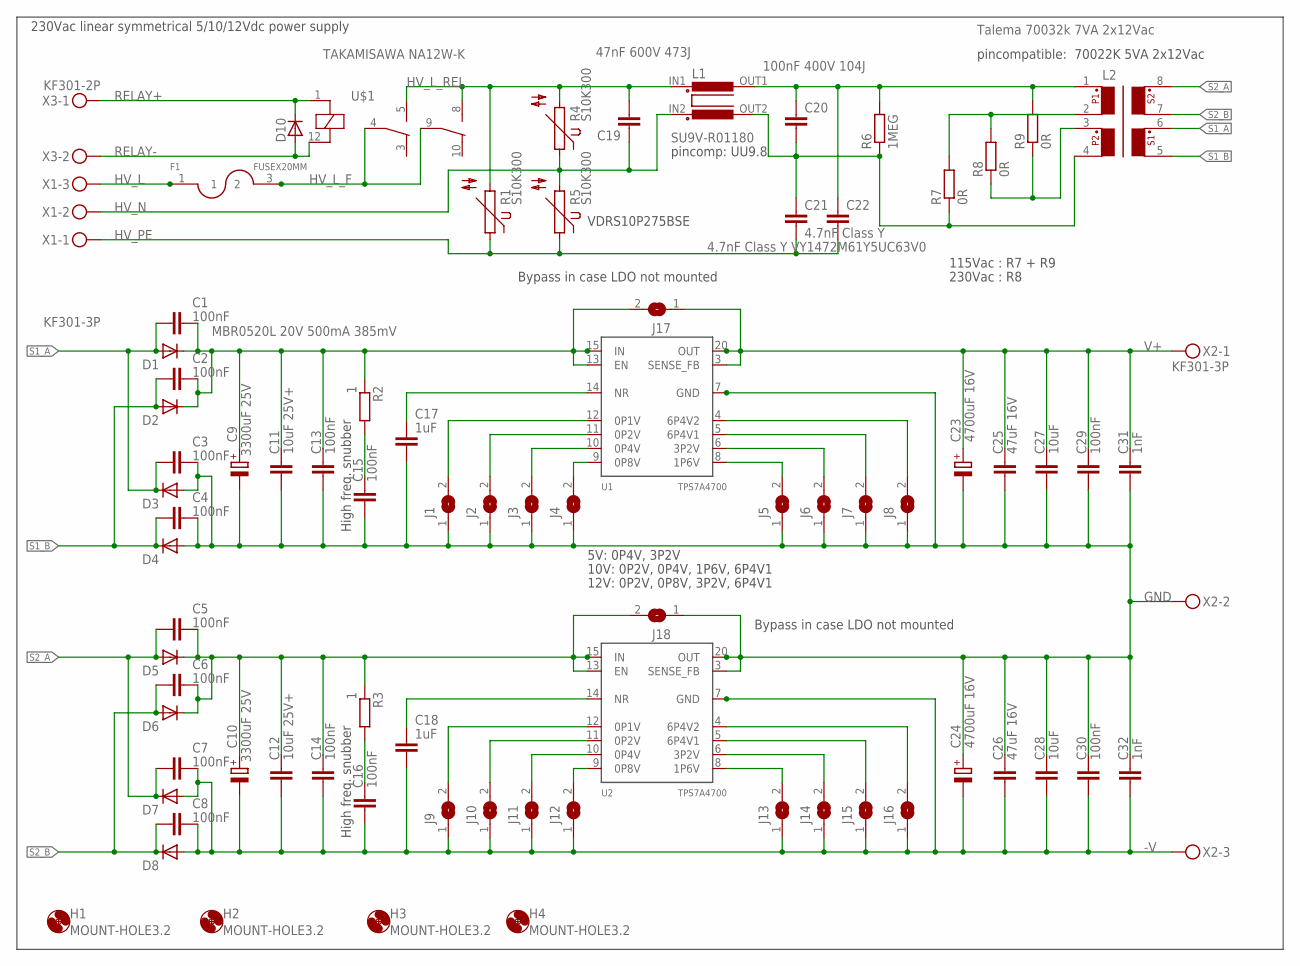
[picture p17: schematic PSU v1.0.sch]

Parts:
C1, C2, C3, C4, C5, C6, C7, C8, C13, C14, C15, C16, C29, C30: 100nF; C0603
C9, C10: 3300uF 25V; E7,5-16
C11, C12: 10uF 25V+; C1206
C17, C18: 1uF; C0603
C19: 47nF 600V 473J; C102-054X133
C20: 100nF 400V 104J; C102-064X133
C21: 4.7nF Class Y VY1472M61Y5UC63V0; C102-043X133
C22: 4.7nF Class Y; C102-043X133
C23, C24: 4700uF 16V; E7,5-16
C25, C26: 47uF 16V; C1210
C27, C28: 10uF; C1206
C31, C32: 1nF; C0603
D1: MBR0520L 20V 500mA 385mV; SOD123
D2, D3, D4, D5, D6, D7, D8: D-SOD123; SOD123
D10: ES1A 50V 1A 25ns; SOD123
F1: FUSEX20MM; FUSE_5MM
H1, H2, H3, H4: MOUNT-HOLE3.2; 3,2
J1, J2, J3, J4, J5, J6, J7, J8, J9, J10, J11, J12, J13, J14, J15, J16, J17, J18: SJ
L1: SU9V-R01180
L2: Talema 70032k 7VA 2x12Vac; TALEMA_70000
R1, R4, R5: S10K300
R2, R3: 1; R0603
R6: 1MEG; 0309/12
R7, R8, R9: 0R; 0204/7
U1, U2: TPS7A4700; VQFN20
U$1: TAKAMISAWA NA12W-K; NA_RELAY
X1, X2: KF301-3P
X3: KF301-2P

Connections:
-V: C7.2, C8.2, C10.-, C12.1, C14.1, C16.1, C18.1, C24.-, C26.2, C28.1, C30.1, C32.1, D7.2 (A), D8.2 (A), J9.1, J10.1, J11.1, J12.1, J13.1, J14.1, J15.1, J16.1, U2.7 (GND), U2.17 (GND), U2.18 (GND), U2.19 (GND), U2.21 (GND), X2.3
GND: C3.2, C4.2, C9.-, C11.1, C13.1, C15.1, C17.1, C23.-, C24.+, C25.2, C26.1, C27.1, C28.2, C29.1, C30.2, C31.1, C32.2, D3.2 (A), D4.2 (A), J1.1, J2.1, J3.1, J4.1, J5.1, J6.1, J7.1, J8.1, J18.1, U1.7 (GND), U1.17 (GND), U1.18 (GND), U1.19 (GND), U1.21 (GND), U2.1 (OUT), U2.3 (SENSE_FB), U2.20 (OUT), X2.2
HV_L: F1.1, F1.2 (3), X1.3
HV_L_F: F1.3 (2), F1.4, U$1.4 (A), U$1.9 (B)
HV_L_REL: C19.1, L1.IN1, R1.2, R4.2, U$1.5 (A_NO), U$1.8 (B_NO)
HV_N: C19.2, L1.IN2, R4.1, R5.2, X1.2
HV_PE: C21.2, C22.2, R1.1, R5.1, X1.1
unnamed: C5.2, C6.2, C10.+, C12.2, C14.2, D5.1 (C), D6.1 (C), J18.2, R3.1, U2.13 (EN), U2.15 (IN), U2.16 (IN)
unnamed: C16.2, R3.2
unnamed: C20.1, C22.1, L1.OUT1, L2.1, R6.2, R9.2
unnamed: C20.2, C21.1, L1.OUT2, L2.4, R6.1, R7.1
unnamed: C15.2, R2.2
unnamed: C18.2, U2.14 (NR)
unnamed: L2.2, R7.2, R8.2
unnamed: L2.3, R8.1, R9.1
unnamed: C1.2, C2.2, C9.+, C11.2, C13.2, D1.1 (C), D2.1 (C), J17.2, R2.1, U1.13 (EN), U1.15 (IN), U1.16 (IN)
unnamed: J13.2, U2.8 (1P6V)
unnamed: J14.2, U2.6 (3P2V)
unnamed: C17.2, U1.14 (NR)
unnamed: J15.2, U2.5 (6P4V1)
unnamed: J5.2, U1.8 (1P6V)
unnamed: J6.2, U1.6 (3P2V)
unnamed: J7.2, U1.5 (6P4V1)
unnamed: J8.2, U1.4 (6P4V2)
unnamed: J16.2, U2.4 (6P4V2)
unnamed: J1.2, U1.12 (0P1V)
unnamed: J2.2, U1.11 (0P2V)
unnamed: J3.2, U1.10 (0P4V)
unnamed: J4.2, U1.9 (0P8V)
unnamed: J9.2, U2.12 (0P1V)
unnamed: J10.2, U2.11 (0P2V)
unnamed: J11.2, U2.10 (0P4V)
unnamed: J12.2, U2.9 (0P8V)
RELAY+: D10.1 (C), U$1.1 (C+), X3.2
RELAY-: D10.2 (A), U$1.12 (C-), X3.3
S1_A: C1.1, C3.1, D1.2 (A), D3.1 (C), L2.6
S1_B: C2.1, C4.1, D2.2 (A), D4.1 (C), L2.5
S2_A: C5.1, C7.1, D5.2 (A), D7.1 (C), L2.8
S2_B: C6.1, C8.1, D6.2 (A), D8.1 (C), L2.7
V+: C23.+, C25.1, C27.2, C29.2, C31.2, J17.1, U1.1 (OUT), U1.3 (SENSE_FB), U1.20 (OUT), X2.1

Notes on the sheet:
230Vac linear symmetrical 5/10/12Vdc power supply
VDRS10P275BSE
10V: 0P2V, 0P4V, 1P6V, 6P4V1
12V: 0P2V, 0P8V, 3P2V, 6P4V1
5V: 0P4V, 3P2V
Bypass in case LDO not mounted
High freq. snubber
115Vac : R7 + R9
230Vac : R8
pincompatible: 70022K 5VA 2x12Vac
pincomp: UU9.8

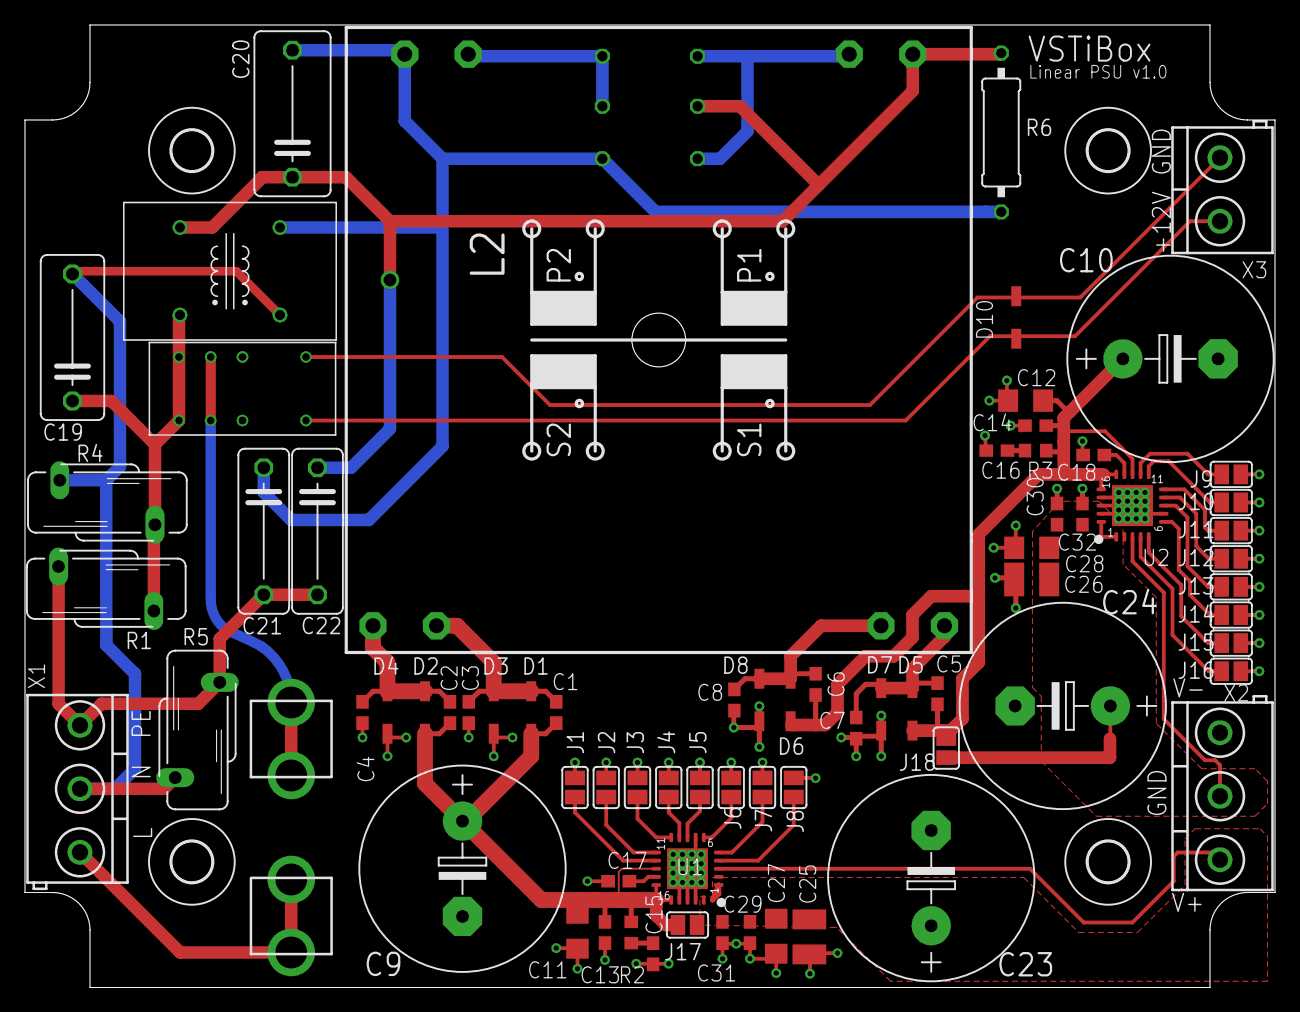
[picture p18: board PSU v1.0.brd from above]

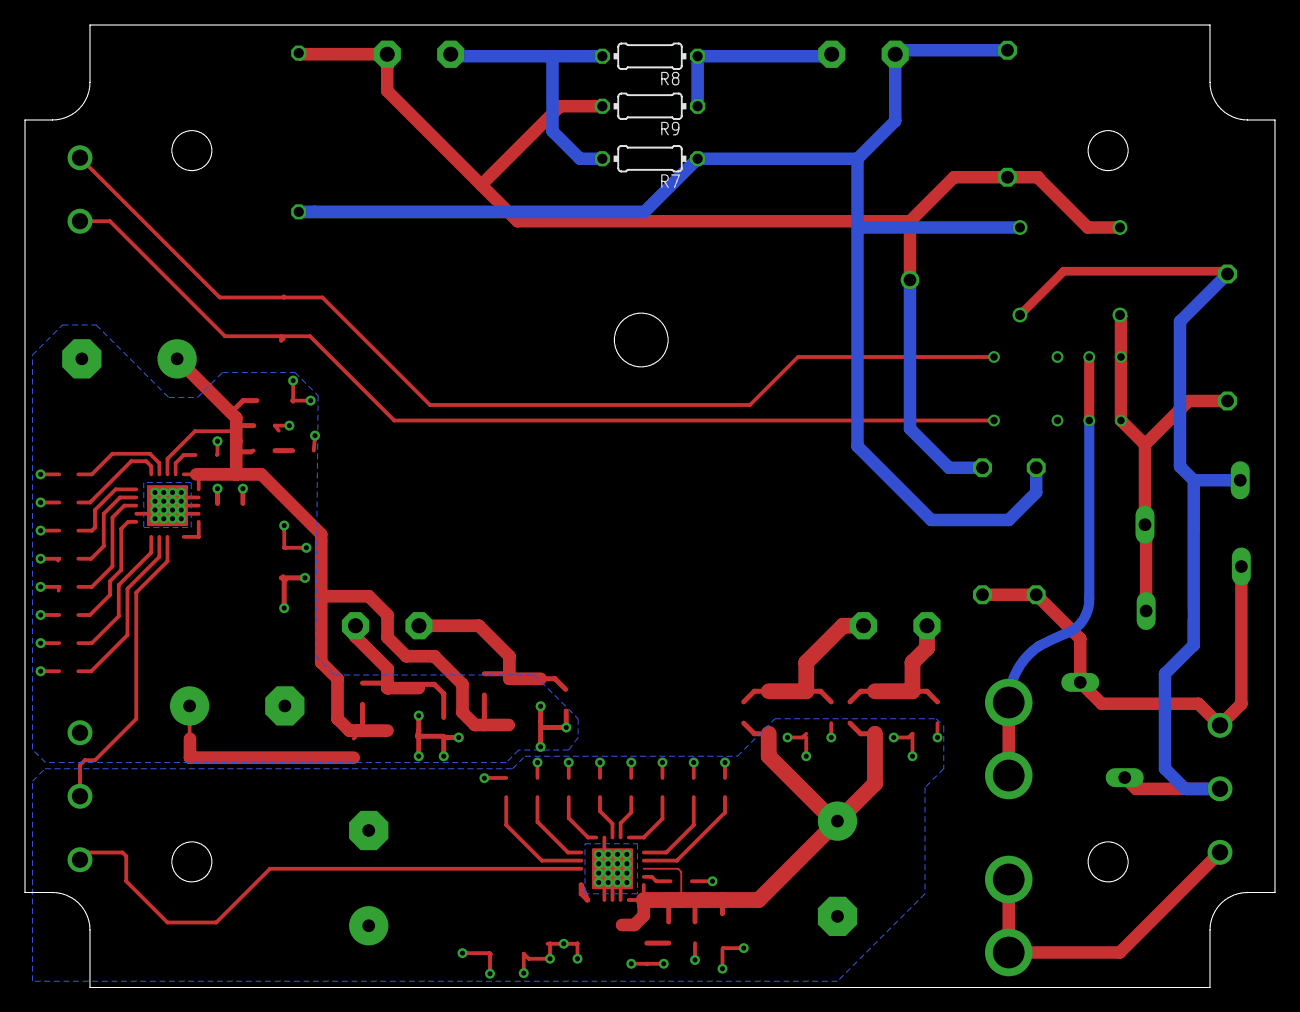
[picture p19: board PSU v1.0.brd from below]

Board: 2 copper layers, 100.0 x 77.0 mm, 82 parts (3 on the bottom side), 40 nets.

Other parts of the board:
U$2: JBK_LOGO_SMALL

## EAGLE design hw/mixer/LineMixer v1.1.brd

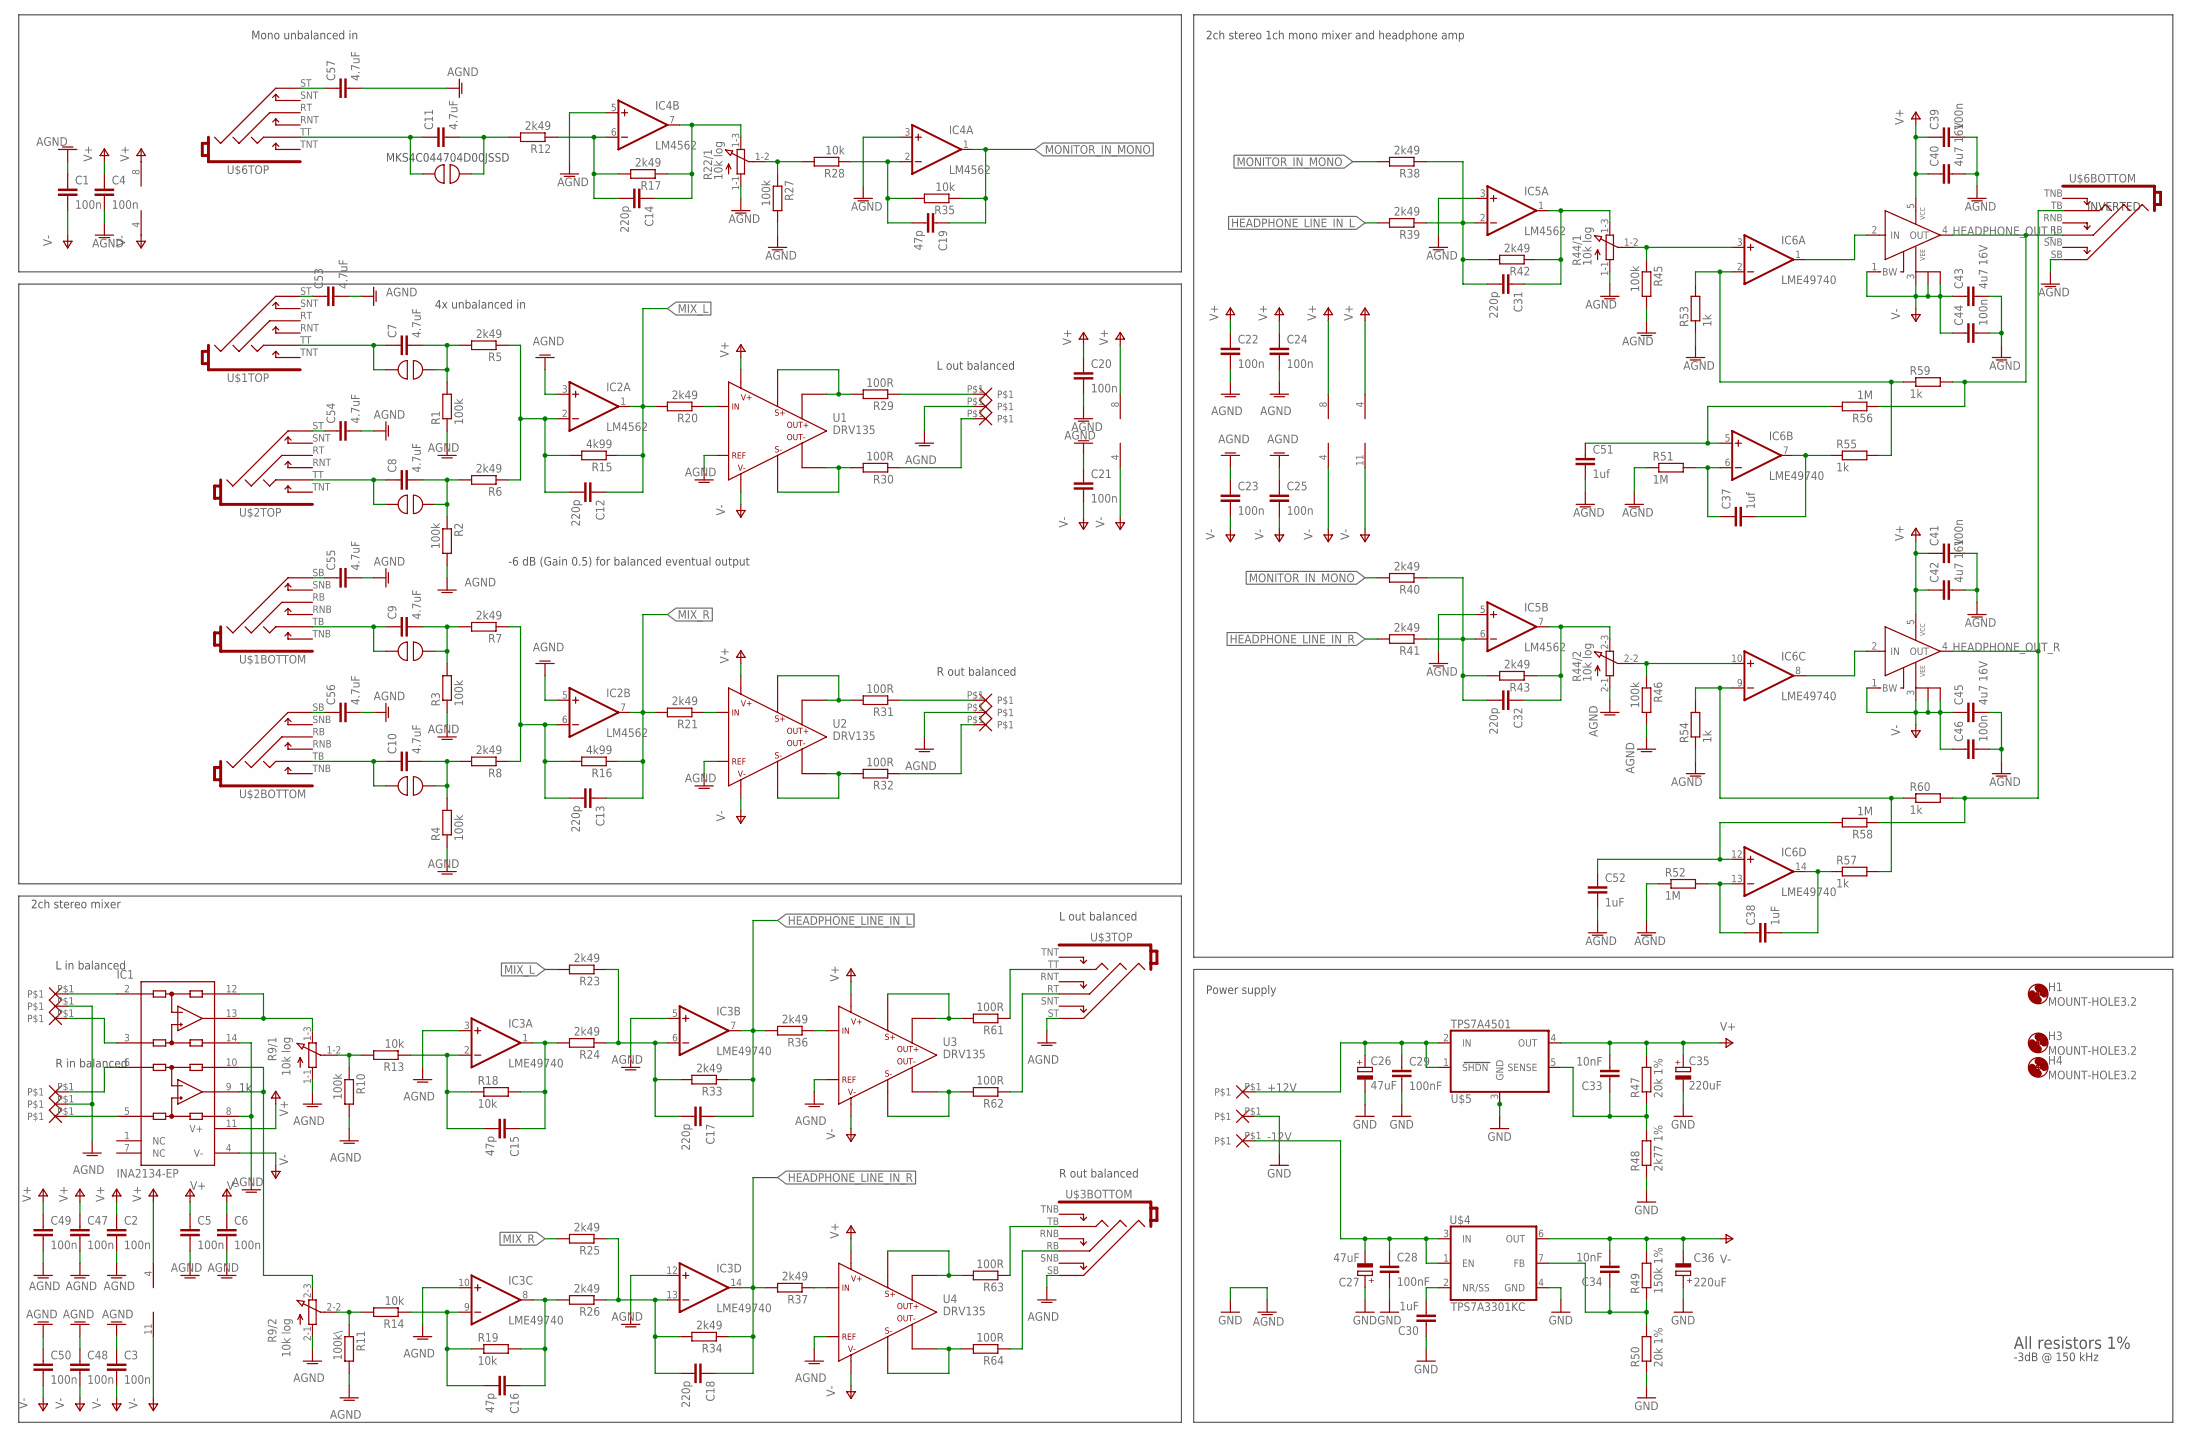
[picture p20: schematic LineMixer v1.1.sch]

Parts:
C1, C2, C3, C4, C5, C6, C20, C21, C22, C23, C24, C25, C39, C41, C44, C46, C47, C48, C49, C50: 100n; C0603
C7, C8, C9, C10, C11, C53, C54, C55, C56, C57: 4.7uF; C15B7
C12, C13, C14, C17, C18, C31, C32: 220p; C0603K
C15, C16, C19: 47p; C0603K
C26, C27: 47uF; D/7343-31R
C28, C29: 100nF; C0603
C30, C38, C52: 1uF; C0603
C33, C34: 10nF; C0603
C35, C36: 220uF; D/7343-31R
C37, C51: 1uf; C0603
C40, C42, C43, C45: 4u7 16V; C1206
H1, H3, H4: MOUNT-HOLE3.2; 3,2
IC1: INA2134-EP; SO14
IC2, IC4, IC5: LM4562; SO08
IC3, IC6: LME49740; SO14
IC7, IC8: LME49600; TS5B
R1, R2, R3, R4, R10, R27, R45, R46: 100k; 0207/7
R5, R6, R7, R8, R12, R17, R20, R21, R23, R24, R25, R26, R33, R34, R36, R37, R38, R39, R40, R41, R42, R43: 2k49; 0207/7
R9, R22, R44: 10k log; 3RP/1610G
R11: 100k\; 0207/7
R13, R14, R18, R19, R28, R35: 10k; 0207/7
R15, R16: 4k99; 0207/7
R29, R30, R31, R32, R61, R62, R63, R64: 100R; 0207/7
R47, R50: 20k 1%; R0603
R48: 2k77 1%; R0603
R49: 150k 1%; R0603
R51, R52, R56, R58: 1M; 0207/7
R53, R54, R55, R57, R59, R60: 1k; 0207/7
S1, S2, S3, S4, S5: SOLDERLINK
U1, U2, U3, U4: DRV135; SO-8
U$1, U$2, U$3, U$6: NSJ12HF-1
U$4: TPS7A3301KC; TO220-7
U$5: TPS7A4501; SOT223-5
U$7, U$8, U$10, U$11, U$12, U$13, U$14, U$15, U$16, U$17, U$18, U$19, U$20, U$21, U$22: PAD1.5MM; PAD_1.5MM

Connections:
+12V: C26.+, C29.1, U$5.1 (SHDN), U$5.2 (IN), U$20.P$1
-12V: C27.-, C28.1, U$4.1 (EN), U$4.3 (IN), U$22.P$1
AGND: C1.1, C2.2, C3.1, C4.2, C5.2, C6.2, C20.2, C21.1, C22.2, C23.1, C24.2, C25.1, C26.-, C27.+, C28.2, C29.2, C30.1, C35.-, C36.+, C39.2, C40.2, C41.2, C42.2, C43.2, C44.2, C45.2, C46.2, C47.2, C48.1, C49.2, C50.1, C51.2, C52.2, C53.2, C54.2, C55.2, C56.2, C57.2, IC1.8 (REFB), IC1.14 (REFA), IC2.3 (+IN), IC2.5 (+IN), IC3.3 (+IN), IC3.5 (+IN), IC3.10 (+IN), IC3.12 (+IN), IC4.3 (+IN), IC4.5 (+IN), IC5.3 (+IN), IC5.5 (+IN), R1.1, R2.2, R3.1, R4.1, R9.1-1 (A), R9.2-1 (A), R10.2, R11.2, R22.1-1 (A), R27.2, R44.1-1 (A), R44.2-1 (A), R45.2, R46.2, R48.1, R50.1, R51.1, R52.1, R53.1, R54.1, U1.P3 (REF), U2.P3 (REF), U3.P3 (REF), U4.P3 (REF), U$3.SB (S), U$3.ST (S), U$4.4 (GND), U$5.3 (GND), U$5.TAB (GND), U$6.SB (S), U$8.P$1, U$12.P$1, U$15.P$1, U$18.P$1, U$21.P$1
HEADPHONE_LINE_IN_L: C17.1, IC3.7 (OUT), R33.1, R36.2, R39.2
HEADPHONE_LINE_IN_R: C18.1, IC3.14 (OUT), R34.1, R37.2, R41.2
HEADPHONE_OUT_L: IC7.4 (OUT), R56.1, R59.2, U$6.RB (R)
HEADPHONE_OUT_R: IC8.4 (OUT), R58.1, R60.2, U$6.TB (T)
MIX_L: C12.1, IC2.1 (OUT), R15.1, R20.2, R23.2
MIX_R: C13.1, IC2.7 (OUT), R16.1, R21.2, R25.2
MONITOR_IN_MONO: C19.1, IC4.1 (OUT), R35.1, R38.2, R40.2
MONITOR_IN_MONO1: C14.1, IC4.7 (OUT), R17.1, R22.1-3 (E)
unnamed: R63.2, U4.P7 (SENSE+), U4.P8 (OUT+)
unnamed: IC1.3 (+INA), U$10.P$1
unnamed: C9.2, R3.2, R7.2, S3.P$1
unnamed: R61.2, U3.P7 (SENSE+), U3.P8 (OUT+)
unnamed: C7.2, R1.2, R5.2, S1.P$1
unnamed: C8.2, R2.1, R6.2, S2.P$1
unnamed: C32.1, IC5.7 (OUT), R43.1, R44.2-3 (E)
unnamed: C15.2, IC3.2 (-IN), R13.1, R18.1
unnamed: C10.2, R4.2, R8.2, S4.P$1
unnamed: IC1.12 (SENSEA), IC1.13 (OUTA), R9.1-3 (E)
unnamed: R36.1, U3.P4 (IN)
unnamed: IC1.2 (-INA), U$7.P$1
unnamed: C32.2, IC5.6 (-IN), R40.1, R41.1, R43.2
unnamed: C16.2, IC3.9 (-IN), R14.1, R19.1
unnamed: R37.1, U4.P4 (IN)
unnamed: IC1.6 (-INB), U$11.P$1
unnamed: R62.1, U$3.RT (R)
unnamed: IC1.5 (+INB), U$13.P$1
unnamed: R64.1, U$3.RB (R)
unnamed: IC1.9 (OUTB), IC1.10 (SENSEB), R9.2-3 (E)
unnamed: C11.1, S5.P$2, U$6.TT (T)
unnamed: C34.1, R49.1, R50.2, U$4.7 (FB)
unnamed: IC6.10 (+IN), R44.2-2 (S), R46.1
unnamed: C12.2, IC2.2 (-IN), R5.1, R6.1, R15.2
unnamed: R29.2, U1.P7 (SENSE+), U1.P8 (OUT+)
unnamed: C15.1, IC3.1 (OUT), R18.2, R24.2
unnamed: C14.2, IC4.6 (-IN), R12.1, R17.2
unnamed: R20.1, U1.P4 (IN)
unnamed: C11.2, R12.2, S5.P$1
unnamed: C18.2, IC3.13 (-IN), R25.1, R26.1, R34.2
unnamed: R30.1, U$19.P$1
unnamed: R29.1, U$17.P$1
unnamed: C31.1, IC5.1 (OUT), R42.1, R44.1-3 (E)
unnamed: R30.2, U1.P1 (OUT-), U1.P2 (SENSE-)
unnamed: R21.1, U2.P4 (IN)
unnamed: C13.2, IC2.6 (-IN), R7.1, R8.1, R16.2
unnamed: C17.2, IC3.6 (-IN), R23.1, R24.1, R33.2
unnamed: R31.1, U$14.P$1
unnamed: C31.2, IC5.2 (-IN), R38.1, R39.1, R42.2
unnamed: R32.1, U$16.P$1
unnamed: R32.2, U2.P1 (OUT-), U2.P2 (SENSE-)
unnamed: R31.2, U2.P7 (SENSE+), U2.P8 (OUT+)
unnamed: IC6.3 (+IN), R44.1-2 (S), R45.1
unnamed: C16.1, IC3.8 (OUT), R19.2, R26.2
unnamed: IC6.2 (-IN), R53.2, R55.2, R59.1
unnamed: R61.1, U$3.TT (T)
unnamed: R62.2, U3.P1 (OUT-), U3.P2 (SENSE-)
unnamed: IC6.1 (OUT), IC7.2 (IN)
unnamed: C37.1, IC6.6 (-IN), R51.2
unnamed: C37.2, IC6.7 (OUT), R55.1
unnamed: C51.1, IC6.5 (+IN), R56.2
unnamed: IC6.9 (-IN), R54.2, R57.2, R60.1
unnamed: IC6.8 (OUT), IC8.2 (IN)
unnamed: R9.1-2 (S), R10.1, R13.2
unnamed: C38.2, IC6.14 (OUT), R57.1
unnamed: C38.1, IC6.13 (-IN), R52.2
unnamed: R9.2-2 (S), R11.1, R14.2
unnamed: C52.1, IC6.12 (+IN), R58.2
unnamed: C19.2, IC4.2 (-IN), R28.1, R35.2
unnamed: R22.1-2 (S), R27.1, R28.2
unnamed: R63.1, U$3.TB (T)
unnamed: C30.2, U$4.2 (NR/SS)
unnamed: R64.2, U4.P1 (OUT-), U4.P2 (SENSE-)
unnamed: C7.1, S1.P$2, U$1.TT (T)
unnamed: C8.1, S2.P$2, U$2.TT (T)
unnamed: C53.1, U$1.ST (S)
unnamed: C57.1, U$6.ST (S)
unnamed: C54.1, U$2.ST (S)
unnamed: C9.1, S3.P$2, U$1.TB (T)
unnamed: C10.1, S4.P$2, U$2.TB (T)
unnamed: C55.1, U$1.SB (S)
unnamed: C56.1, U$2.SB (S)
unnamed: C33.1, R47.1, R48.2, U$5.5 (SENSE)
V+: C2.1, C4.1, C5.1, C20.1, C22.1, C24.1, C33.2, C35.+, C39.1, C40.1, C41.1, C42.1, C47.1, C49.1, IC1.11 (V+), IC2.8 (V+), IC3.4 (V+), IC4.8 (V+), IC5.8 (V+), IC6.4 (V+), IC7.5 (VCC), IC8.5 (VCC), R47.2, U1.P6 (V+), U2.P6 (V+), U3.P6 (V+), U4.P6 (V+), U$5.4 (OUT)
V-: C1.2, C3.2, C6.1, C21.2, C23.2, C25.2, C34.2, C36.-, C43.1, C44.1, C45.1, C46.1, C48.2, C50.2, IC1.4 (V-), IC2.4 (V-), IC3.11 (V-), IC4.4 (V-), IC5.4 (V-), IC6.11 (V-), IC7.1 (BW), IC7.3 (VEE), IC7.TH@1 (VEE), IC7.TH@2 (VEE), IC8.1 (BW), IC8.3 (VEE), IC8.TH@1 (VEE), IC8.TH@2 (VEE), R49.2, U1.P5 (V-), U2.P5 (V-), U3.P5 (V-), U4.P5 (V-), U$4.6 (OUT)

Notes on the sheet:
4x unbalanced in
L out balanced
2ch stereo 1ch mono mixer and headphone amp
-6 dB (Gain 0.5) for balanced eventual output
L in balanced
R in balanced
R out balanced
Mono unbalanced in
2ch stereo mixer
Power supply
-3dB @ 150 kHz
INVERTED
All resistors 1%
MKS4C044704D00JSSD

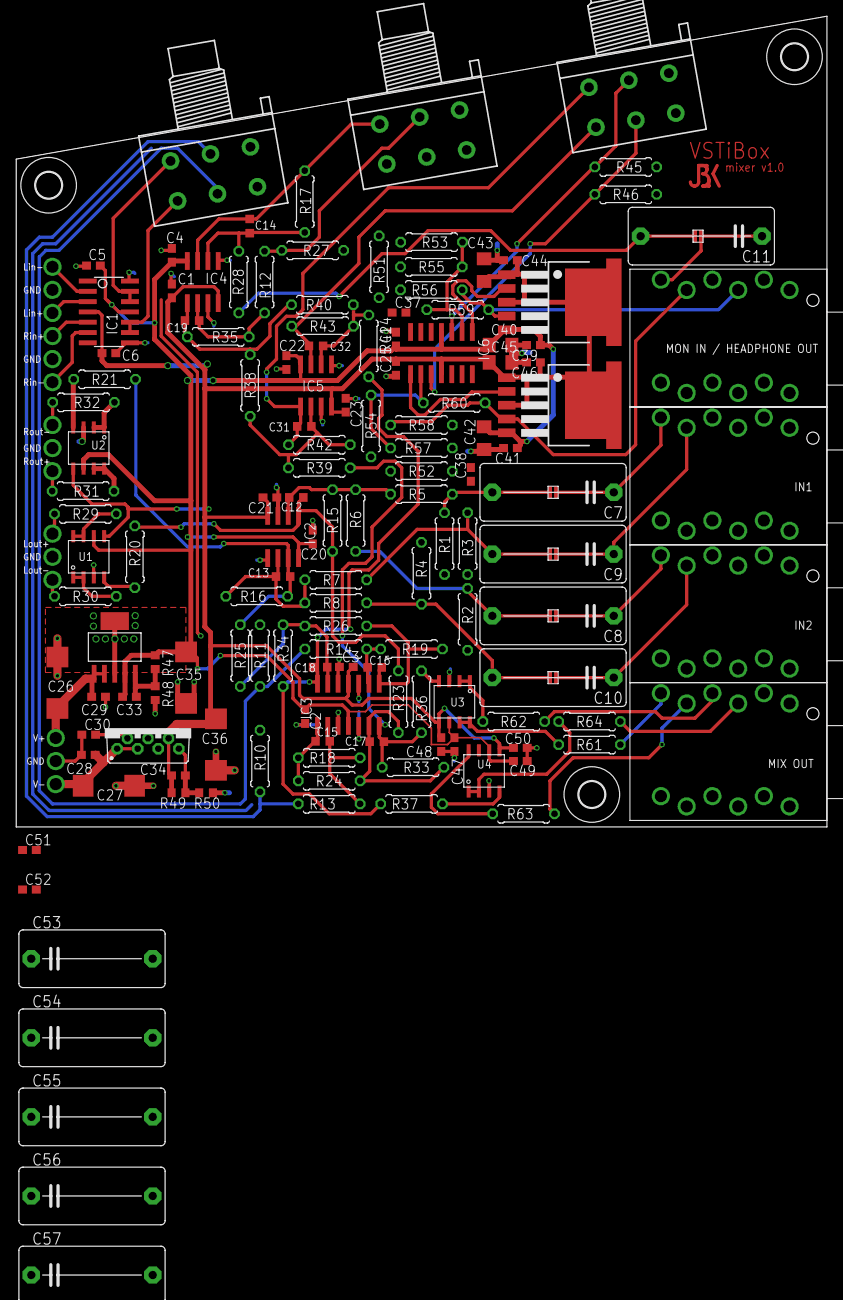
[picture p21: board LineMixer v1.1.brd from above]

Board: 2 copper layers, 100.0 x 100.0 mm, 163 parts (0 on the bottom side), 86 nets.

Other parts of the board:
U$9: JBK_LOGO_SMALL_COPPER

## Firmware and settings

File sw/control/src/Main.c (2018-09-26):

/**************************************************************************
*   Main.c VSTiBox button breakout
***************************************************************************/

#include "application.h"

//#define SWD	// Select either SWD or LED PWM functionality! They share the same pin.
 
// Board options
#define ENC0
#define ENC1
#define ENC2
#define ENC3

//#define ANA

// Defines
#define ABS(x)			(x>0 ? x:-x)
#define ID_INVALID 		0xFF
#define PROTOCOL_SIZE	5				// CMD, ID, BYTE0, BYTE1, CHK

#define PWM_FREQ	800		// Hz
#define PWM_PERIOD ((1.0/PWM_FREQ)*SystemClock) 

#define FUNC0 (0)
#define FUNC1 (1)
#define FUNC2 (2)
#define FUNC3 (3)
#define DIGITAL_MODE (1<<7)

#define PULL_UP (2<<3)

// Left to right:
// LED 1, 3, 2, 4
#define LEDR1		0		// P0.10	T16B0_MAT2	 	+ SWCLK
#define LEDR2		1		// P0.1		T32B0_MAT2		+ ISP
//#define LEDR3		2		// P1.7		T32B0_MAT1 ==> NOW TX!
#define LEDR3		2		// P2.6		PIO2_6 !!!
#define LEDR4		3		// P0.11	T32B0_MAT3
#define LEDG1		4		// P1.2 	T32B1_MAT1
#define LEDG2		5		// P0.8		T16B0_MAT0		
//#define LEDG3		6		// P1.6		T32B0_MAT0 ==> NOW RX!
#define LEDG3		6		// P1.5		PIO1_5 !!!
#define LEDG4		7		// P1.10	T16B1_MAT1
#define LEDB1		8		// P1.1 	T32B1_MAT0
#define LEDB2		9		// P1.9		T16B1_MAT0
#define LEDB3		10		// p1.3		T32B1_MAT2		+ SWDIO
#define LEDB4		11		// P0.9		T16B0_MAT1

#define BTN1	(!(GPIOGetValue(2, 4)))		//	P2.4
#define BTN2	(!(GPIOGetValue(2, 5)))		//	P2.5
#define BTN3	(!(GPIOGetValue(3, 1)))		//	P3.1
#define BTN4	(!(GPIOGetValue(2, 7)))		//	P2.7
#define E1_I	(!(GPIOGetValue(2, 10)))	//	P2.10
#define E2_I	(!(GPIOGetValue(2, 2)))		//	P2.2
#define E3_I	(!(GPIOGetValue(3, 2)))		//	P3.2
#define E4_I	(!(GPIOGetValue(3, 4)))		//  P3.4

#define CMD_SET_ID 		(0 | (1<<7))		// 0x80
#define CMD_BTN 			(1 | (1<<7))		// 0x81
#define CMD_RT_BTN 		(2 | (1<<7))		// 0x82
#define CMD_RT_DELTA(n) ((3+n) | (1<<7))	// n = 0..3  0x83/0x84/0x85/0x86
#define CMD_LED_VALUE	(7 | (1<<7))		// 0x87
#define CMD_ACT_LED 		(8 | (1<<7))		// 0x88
#define CMD_TEMP 			(9 | (1<<7))		// 0x89
#define CMD_ANA			(11 | (1<<7))		// 0x8B

#pragma pack(1)   	/* byte alignment */
typedef struct
{
		uint8_t cmd;
		uint8_t id;
		uint16_t val;
		uint8_t chk;
}Msg_t;
#pragma pack()		/* reset to default alignment */ 

typedef struct
{
	uint8_t port; 
	uint8_t pin;
	uint8_t val;
	uint16_t debounce;
}Input_t;

typedef struct 
{
	uint8_t irq;
	int8_t delta;
	Input_t A;
	Input_t B;
}Encoder_t;

extern volatile uint32_t UART_Status;
extern volatile uint32_t UART_TxEmpty;
extern volatile uint8_t  UART_RxBuff[BUFSIZE];
extern volatile uint32_t UART_RxCount;
volatile uint16_t AD7_val;       	/* Last converted AD7 value */
uint32_t systick=0;

float led[] = {	0.0, 0.0, 0.0, 0.0, 0.0, 0.0, 	// Red		0...3
				0.0, 0.0, 0.0, 0.0, 0.0, 0.0, 	// Green	0...3
				0.0, 0.0, 0.0, 0.0, 0.0, 0.0}; 	// Blue		0...3
									 
					// 	irq		d  		Aport 	Apin 	prevA	debounce	Bport 	Bpin 	prevB	debounce
Encoder_t enc_ab[] = {	{0, 	0,		{0,		7, 		0,		0},			{2,		9,		0,		0}},
						{0,		0,		{0,		6, 		0,		0},			{2,		1,		0,		0}},
						{0,		0,		{3,		0, 		0,		0},			{2,		3, 		0,		0}},
						{0,		0,		{2,		11, 	0,		0},			{3,		3,		0,		0}}};
		   
				// 	Port	pin		val	debounce
Input_t	btn[] =   {{2,		4, 		0,		0},	
					{2,		5, 		0,		0},	
					{3,		1, 		0,		0},	
					{2,		7, 		0,		0}};	
Input_t	enc_i[] =  {{2,		10,		0,		0},	
					{2,		2, 		0,		0},	
					{3,		2, 		0,		0},	
					{3,		4, 		0,		0}};	

void ClockInit(void);
void IO_Init(void);
void LedsInit(void);
void LedPWM(uint8_t led, float pwm);
void Led_value(uint16_t value);
void Led_activate(void);
void sendMessage(Msg_t *msg);
void ADC_init (void); 
void ADC_start(void);
static __inline void updateEnc(Encoder_t *enc);
static __inline uint8_t updateBtn(Input_t *inp);

/*----------------------------------------------------------------------------
  MAIN function
 *----------------------------------------------------------------------------*/
int main (void)                                	/* Main Program               */
{
	uint8_t neededbytes = PROTOCOL_SIZE; 
	uint16_t adc;
	uint8_t doFwd = 0, doReply = 0, doNew = 0;
	uint8_t i;
	int16_t temperature;	// 0.1 deg
	uint8_t tempIrq = 0, btnIrq = 0, rotBtnIrq = 0, adcIrq = 0;
	uint8_t id = ID_INVALID;			// My id
	Msg_t rxMsg;							// Message received
	Msg_t replyMsg;						// Message send in response to request (e.g. Temp)
	Msg_t fwdMsg;							// Message forward : not intended for this slave 
	Msg_t newMsg;							// Message created by the slave (e.g. button press / release / analog changed)
	
	// Huge delay for SWD/SWD to take over before being set to GPIO (shared pin)! Without this delay debugging is 
    // not possible anymore when deselecting SWD/SWD functionality. In this case only the on-chip bootloader can be used
	int n;
	for(n=0;n<2000000;n++)	// 3 sec
	{
		__NOP();
	}
	
	ClockInit();
	GPIOInit();
	IO_Init();
	SysTick_Config(SystemClock/10);          	/* Generate IRQ each ~100 ms   */
	UART_Init(115200);
	ADC_init();
	lm75a_init();
	LedsInit();
			
	while (1)                                   /* Loop forever               */
	{
		/* Systick @ 100ms */
		if(systick == 30)	// Every 3 sec
		{
			systick = 0;
			temperature = lm75a_readTemp();
			tempIrq = 1;
			
			// Check valid ADC value's
			if(AD7_val>3 && AD7_val<1020)	
			{
				if(AD7_val != adc)
				{
					#ifdef ANA
					adcIrq = 1;
					#endif
				}
			}
			adc = AD7_val;	
			ADC_start();		// Start a new ADC conversion
		}
		
		btnIrq |= updateBtn(&btn[0]);
		btnIrq |= updateBtn(&btn[1]);
		btnIrq |= updateBtn(&btn[2]);
		btnIrq |= updateBtn(&btn[3]);
	
#ifdef ENC0		
		rotBtnIrq |= updateBtn(&enc_i[0]);
#else
		updateBtn(&enc_i[0]);
#endif
#ifdef ENC1		
		rotBtnIrq |= updateBtn(&enc_i[1]);
#else
		updateBtn(&enc_i[1]);
#endif
#ifdef ENC2		
		rotBtnIrq |= updateBtn(&enc_i[2]);
#else
		updateBtn(&enc_i[2]);
#endif
#ifdef ENC3		
		rotBtnIrq |= updateBtn(&enc_i[3]);
#else
		updateBtn(&enc_i[3]);
#endif

		updateEnc(&enc_ab[0]);						// Encoder delta 1
		updateEnc(&enc_ab[1]);						// Encoder delta 2
		updateEnc(&enc_ab[2]);						// Encoder delta 3
		updateEnc(&enc_ab[3]);						// Encoder delta 4
		
		/*******************************************/
		/* BUILD NEW MESSAGES IN ORDER OF PRIORITY */
		/*******************************************/
		
		if(!doNew && btnIrq && id!=ID_INVALID)
		{
			// Create btn irq message
			newMsg.cmd = CMD_BTN;
			newMsg.id = id;
			newMsg.val = (btn[0].val << 0) | (btn[1].val << 1) | (btn[2].val << 2) | (btn[3].val << 3) ;
			doNew = 1;
			btnIrq = 0;
		}	
		
		if(!doNew && rotBtnIrq && id!=ID_INVALID)	
		{
			// Create rotary btn irq message
			newMsg.cmd = CMD_RT_BTN;
			newMsg.id = id;
			newMsg.val = (enc_i[0].val << 0) | (enc_i[1].val << 1) | (enc_i[2].val << 2) | (enc_i[3].val << 3) ;
			doNew = 1;
			rotBtnIrq = 0;
		}
		
		for(i=0;i<4;i++)
		{
			if(!doNew && enc_ab[i].irq && id!=ID_INVALID)
			{
				// Create rotary delta irq message
				newMsg.cmd = CMD_RT_DELTA(i);
				newMsg.id = id;
				newMsg.val = (uint16_t)enc_ab[i].delta;
				doNew = 1;
				enc_ab[i].irq = 0;
			}
		}	

		// ADC almost lowest priority
		if(!doNew && adcIrq && id!=ID_INVALID)
		{
			// Create ADC irq message
			newMsg.cmd = CMD_ANA;
			newMsg.id = id;
			newMsg.val = adc;
			doNew = 1;
			adcIrq = 0;
		}	

		// Temperature lowest priority
		if(!doNew && tempIrq && id!=ID_INVALID)
		{
			// Create temperature irq message
			newMsg.cmd = CMD_TEMP;
			newMsg.id = id;
			newMsg.val = temperature;
			doNew = 1;
			tempIrq = 0;
		}		
		
		/***************************/
		/* SEND AND RECEIVE ********/
		/***************************/
		
		// Check if everything has been sent, before making new messages
		if (!doFwd && !doReply && UART_RxCount >= neededbytes )
		{
			if((UART_RxBuff[neededbytes-PROTOCOL_SIZE] & (1<<7)) == 0)
			{
				// Not correct CMD byte
				neededbytes++;
			}
			else
			{
				// Handle 'PROTOCOL_SIZE' bytes
				LPC_UART->IER = IER_THRE | IER_RLS;							/* Disable RBR */
				
				rxMsg.cmd = UART_RxBuff[neededbytes-(PROTOCOL_SIZE-0)]; 
				rxMsg.id = UART_RxBuff[neededbytes-(PROTOCOL_SIZE-1)]; 
				rxMsg.val = ((uint16_t)UART_RxBuff[neededbytes-(PROTOCOL_SIZE-3)] << 8) | UART_RxBuff[neededbytes-(PROTOCOL_SIZE-2)];
				rxMsg.chk = UART_RxBuff[neededbytes-(PROTOCOL_SIZE-4)]; 
				
				// Copy bytes to beginning of buffer
				for(i=neededbytes; i<UART_RxCount; i++)
				{
					UART_RxBuff[i-neededbytes] = UART_RxBuff[i];	
				}
				UART_RxCount -= neededbytes;
				
				LPC_UART->IER = IER_THRE | IER_RLS | IER_RBR;		/* Re-enable RBR */
				
				// Command
				switch(rxMsg.cmd)
				{
					// 0	binary mask	Set ID	Each slave sets it bit				
					// 1	binary mask	Button	binary mask	1 = pressed, 0 = released			CAN BE COMBINED
					// 2	binary mask	Rotary button	binary mask	1 = pressed, 0 = released			
					// 3	binary mask	Rotary delta	 -16383 ... 16384				CANNOT BE COMBINED
					// 4	binary mask	Set leds	0 ... 32768				
					// 5	binary mask		0 ... 32768				
					// 6	binary mask		0 ... 32768				
					// 7	binary mask	Get temperature	 -16383 ... 16384	x 0,1 degrees C			
					// 8	binary mask	Filtered analog value 	0 ... 1023				
						case(CMD_SET_ID):
							for(i=0; i<8; i++)
							{
								if(!(rxMsg.id & (1<<i)))
								{
									// id not taken yet; take it
									id = (1<<i);
									break;
								}
							}
							
							fwdMsg.cmd = CMD_SET_ID; 
							fwdMsg.id = rxMsg.id | id;
							fwdMsg.val = 0;
							doFwd = 1;
							break;
						case(CMD_BTN):
						case(CMD_RT_BTN):
						case(CMD_RT_DELTA(0)):
						case(CMD_RT_DELTA(1)):
						case(CMD_RT_DELTA(2)):
						case(CMD_RT_DELTA(3)):
						case(CMD_ANA):
						case(CMD_TEMP):
							// Simply forward without handling
							fwdMsg.cmd = rxMsg.cmd; 
							fwdMsg.id = rxMsg.id;
							fwdMsg.val = rxMsg.val;
							doFwd = 1;
							break;
						case(CMD_LED_VALUE):
							if(rxMsg.id & id)
							{
								// Handle message
								Led_value(rxMsg.val);
							}

							// Forward message
							fwdMsg.cmd = rxMsg.cmd; 
							fwdMsg.id = rxMsg.id;
							fwdMsg.val = rxMsg.val;
							doFwd = 1;
							break;
						case(CMD_ACT_LED):
							if(rxMsg.id & id)
							{
								// Handle message
								Led_activate();
							}

							// Forward message
							fwdMsg.cmd = rxMsg.cmd; 
							fwdMsg.id = rxMsg.id;
							fwdMsg.val = rxMsg.val;
							doFwd = 1;
							break;
						default:
							// Unknown command!
							break;
				}
				
			}
		}
			
		if(UART_TxEmpty)
		{
			// Ready to send new message 
			if(doFwd)
			{
				doFwd = 0;
				sendMessage(&fwdMsg); 		// Non blocking because of FIFO
			}
			else if(doReply)
			{
				doReply = 0;
				sendMessage(&replyMsg);		// Non blocking because of FIFO
			}
			else if(doNew)
			{
				doNew = 0;
				sendMessage(&newMsg);		// Non blocking because of FIFO
			}
		}
	}
}

static __inline void updateEnc(Encoder_t *enc)
{
	// Rotary position : no debouncing!
	uint8_t tmpA = GPIOGetValue(enc->A.port, enc->A.pin);
	uint8_t tmpB = GPIOGetValue(enc->B.port, enc->B.pin);
	
	if(tmpA && !enc->A.val)		// Risinge edge on A
	{
		if(!tmpB)enc->delta++;
		else enc->delta--;
		enc->irq = 1;
	}
	if(!tmpA && enc->A.val)		// Falling edge on A
	{
		if(tmpB)enc->delta++;
		else enc->delta--;
		enc->irq = 1;
	}
	if(tmpB && !enc->B.val)		// Risinge edge on B
	{
		if(tmpA)enc->delta++;
		else enc->delta--;
		enc->irq = 1;
	}
	if(!tmpB && enc->B.val)		// Falling edge on B
	{
		if(!tmpA)enc->delta++;
		else enc->delta--;
		enc->irq = 1;
	}
	enc->A.val = tmpA;
	enc->B.val = tmpB;
}

static __inline uint8_t updateBtn(Input_t *inp)
{
	uint8_t tmp = GPIOGetValue(inp->port, inp->pin);

	// Respond fast to key press (falling edge), and slowly to release (rising edge) 
	if(!tmp)
	{
		// Input low: key pressed
		inp->debounce = 0;		
		
		// Previously not pressed?
		if(inp->val)
		{
			// Falling edge (key press event)	
			inp->val = tmp;
			return 1;
		}
	}
	else 
	{
		inp->debounce++;
		if(inp->debounce > 2000)	
		{
			inp->debounce = 2000;
			
			// Previously not released?
			if(!inp->val)
			{
				// Rising edge (key release event)
				inp->val = tmp;
				return 1;
			}
		}		
	}
	
	return 0;
}

void sendMessage(Msg_t *msg)
{
	uint8_t arr[5];
	uint8_t *p, i, sum = 0; 
	
	p = (uint8_t*)msg;
	// Calc checksum
	for(i=0;i<4;i++)
	{
		sum+=*p;
		arr[i] = *p++;
	}
	arr[i] = sum & 0x7F;		
	UARTSend( arr, 5 ); 		// Non blocking because of FIFO
}

void SysTick_Handler (void)
{
	systick++;
}

void ClockInit(void)
{
    uint32_t i=31;

    //LPC_SYSCON->WDTOSCCTRL = (0x1<<5) | (0x1F<<0);     //500k/64=7.8kHz, real 8.6kHz
    LPC_SYSCON->PDRUNCFG     &= ~(1 << 5); 	/* Power-up System oscillator */
    for (i = 0; i < 200; i++) __NOP();
	
	LPC_SYSCON->SYSPLLCLKSEL = 1;
	LPC_SYSCON->SYSPLLCLKUEN = 1;
	
	#define MSEL 4 	// M = 5
	#define PSEL 1	// P = 2
	LPC_SYSCON->SYSPLLCTRL    = MSEL |(PSEL<<5);
	LPC_SYSCON->PDRUNCFG     &= ~(1 << 7);          	/* Power-up SYSPLL          */
	while (!(LPC_SYSCON->SYSPLLSTAT & 0x01))__NOP();	/* Wait Until PLL Locked    */
		
    LPC_SYSCON->MAINCLKSEL    = 3;     					/* Select Input clock to system PLL */
    LPC_SYSCON->MAINCLKUEN    = 0x01;               	/* Update MCLK Clock Source */
    LPC_SYSCON->MAINCLKUEN    = 0x00;               	/* Toggle Update Register   */
    LPC_SYSCON->MAINCLKUEN    = 0x01;
    while (!(LPC_SYSCON->MAINCLKUEN & 0x01));       	/* Wait Until Updated       */


    LPC_SYSCON->SYSAHBCLKDIV  = 1;	   //divide by 1
    //                           sys	rom		ram	 flashreg flasha gpio	iocon
    LPC_SYSCON->SYSAHBCLKCTRL = (1<<0)|(1<<1)|(1<<2)|(1<<3)|(1<<4)|(1<<6)|(1<<16);
    LPC_SYSCON->UARTCLKDIV    = 0;	   //divide by 1
    LPC_SYSCON->SSP0CLKDIV    = 0;
    LPC_SYSCON->SSP1CLKDIV    = 0;
}
	
void Led_value(uint16_t value)
{
	uint8_t led_nr = value >> 8;
	uint8_t led_val = value & 0xFF;	

	if(led_nr < 12)
	{
		led[led_nr] = ((float)led_val) / 255.0;
	}
}

void Led_activate()
{
	int i;
	for(i=0;i<12;i++)
	{
		LedPWM(i, led[i]);
	}
}

void IO_Init()
{	
	GPIOSetDir(2, 4, 0);		// BTN1 				// port num, bit position, direction (1 out, 0 input)
	LPC_IOCON->PIO2_4 = PULL_UP | FUNC0;
	
	GPIOSetDir(2, 5, 0);		// BTN2
	LPC_IOCON->PIO2_5 = PULL_UP | FUNC0;
	
	GPIOSetDir(3, 1, 0);		// BTN3
	LPC_IOCON->PIO3_1 = PULL_UP | FUNC0;
	
	GPIOSetDir(2, 7, 0);		// BTN4
	LPC_IOCON->PIO2_7 = PULL_UP | FUNC0;
	
	GPIOSetDir(2, 10, 0);		// E1_I
	LPC_IOCON->PIO2_10 = PULL_UP | FUNC0;
	
	GPIOSetDir(2, 2, 0);		// E2_I
	LPC_IOCON->PIO2_2 = PULL_UP | FUNC0;

	GPIOSetDir(3, 2, 0);		// E3_I
	LPC_IOCON->PIO3_2 = PULL_UP | FUNC0;

	GPIOSetDir(3, 4, 0);		// E4_I	
	LPC_IOCON->PIO3_4 = PULL_UP | FUNC0;
	
	GPIOSetDir(0, 7, 0);		// E1_A
	LPC_IOCON->PIO0_7 = PULL_UP | FUNC0;
	
	GPIOSetDir(0, 6, 0);		// E2_A
	LPC_IOCON->PIO0_6 = PULL_UP | FUNC0;
	
	GPIOSetDir(3, 0, 0);		// E3_A
	LPC_IOCON->PIO3_0 = PULL_UP | FUNC0;
	
	GPIOSetDir(2, 11, 0);		// E4_A
	LPC_IOCON->PIO2_11 = PULL_UP | FUNC0;
	
	GPIOSetDir(2, 9, 0);		// E1_B
	LPC_IOCON->PIO2_9 = PULL_UP | FUNC0;
	
	GPIOSetDir(2, 1, 0);		// E2_B
	LPC_IOCON->PIO2_1 = PULL_UP | FUNC0;
	
	GPIOSetDir(2, 3, 0);		// E3_B
	LPC_IOCON->PIO2_3 = PULL_UP | FUNC0;
	
	GPIOSetDir(3, 3, 0);		// E4_B
	LPC_IOCON->PIO3_3 = PULL_UP | FUNC0;
}

void LedPWM(uint8_t led, float pwm)
{
	uint32_t u32pwm = PWM_PERIOD;
	u32pwm -= (pwm * PWM_PERIOD);

	switch(led)
	{
		case(LEDR1):
			LPC_TMR16B0->MR2 = u32pwm;
			break;
		case(LEDR2):
			LPC_TMR32B0->MR2 = u32pwm;
			break;
		case(LEDR3):
			LPC_TMR32B0->MR1 = u32pwm;	// soft PWM!
			if(pwm == 0.0)
			{
				GPIOSetValue(2, 6, 0);
			}
			break;
		case(LEDR4):
			LPC_TMR32B0->MR3 = u32pwm;
			break;
		case(LEDG1):
			LPC_TMR32B1->MR1 = u32pwm;
			break;
		case(LEDG2):
			LPC_TMR16B0->MR0 = u32pwm;
			break;
		case(LEDG3):
			LPC_TMR16B1->MR2 = u32pwm;	// soft PWM!
			if(pwm == 0.0)
			{
				GPIOSetValue(1, 5, 0);
			}
			break;
		case(LEDG4):
			LPC_TMR16B1->MR1 = u32pwm;
			break;
		case(LEDB1):
			LPC_TMR32B1->MR0 = u32pwm;
			break;
		case(LEDB2):
			LPC_TMR16B1->MR0 = u32pwm;
			break;
		case(LEDB3):
			LPC_TMR32B1->MR2 = u32pwm;
			break;
		case(LEDB4):
			LPC_TMR16B0->MR1 = u32pwm;
			break;
		default:
			break;
	}
}

void LedsInit(void)
{
#ifndef SWD	
	LPC_IOCON->SWCLK_PIO0_10 = FUNC3;				// LEDR1 0	// P0.10	T16B0_MAT2	 	+ SWCLK
#endif	
	LPC_IOCON->PIO0_1 =	FUNC2;						// LEDR2 1	// P0.1		T32B0_MAT2		+ ISP
	LPC_IOCON->PIO2_6 =	FUNC0;						// LEDR3 2	// P2.6		PIO2_6 !!! ==> soft pwm on CT32B0_MAT1
	GPIOSetDir(2, 6, 1);
	GPIOSetValue(2, 6, 0);
	LPC_IOCON->R_PIO0_11 = FUNC3|DIGITAL_MODE;		// LEDR4 3	// P0.11	T32B0_MAT3 	// todo (1<<6) ?!
	LPC_IOCON->R_PIO1_2 = FUNC3|DIGITAL_MODE;		// LEDG1 4	// P1.2 	T32B1_MAT1
	LPC_IOCON->PIO0_8 = FUNC2; 						// LEDG2 5 	// P0.8		T16B0_MAT0		
	LPC_IOCON->PIO1_5 =	FUNC0;						// LEDG3 6	// P1.5		PIO1_5 !!! ==> soft pwm on CT16B1_MAT2
	GPIOSetDir(1, 5, 1);
	GPIOSetValue(1, 5, 0);
	LPC_IOCON->PIO1_10 = FUNC2;						// LEDG4 7	// P1.10	T16B1_MAT1
	LPC_IOCON->R_PIO1_1 = FUNC3|DIGITAL_MODE;		// LEDB1 8	// P1.1 	T32B1_MAT0
	LPC_IOCON->PIO1_9 = FUNC1; 						// LEDB2 9	// P1.9		T16B1_MAT0
#ifndef SWD
	LPC_IOCON->SWDIO_PIO1_3 = FUNC3|DIGITAL_MODE;	// LEDB3 10	// p1.3		T32B1_MAT2		+ SWDIO
#endif	
	LPC_IOCON->PIO0_9 = FUNC2;						// LEDB4 11	// P0.9		T16B0_MAT1
	
	LPC_SYSCON->SYSAHBCLKCTRL |= (1<<7)|(1<<8)|(1<<9)|(1<<10); 	// Enable clock to CT16B0/1, CT32B0/1
	
	// T16B0	: G2=MAT0, 	B4=MAT1, 	R1=MAT2, 
	// T16B1	: B2=MAT0, 	G4=MAT1,  	g3s=MAT2
	// T32B0	: 			r3s=MAT1	R2=MAT2, 	R4=MAT3, 
	// T32B1	: B1=MAT0, 	G1=MAT1, 	B3=MAT2
	
	/* CT16B0 */
	LPC_TMR16B0->EMR = (2<<8)|(2<<6)|(2<<4)|(1<<2)|(1<<1)|(1<<0);	// External match : set high on match 0,1,2 
	LPC_TMR16B0->PWMC = (1<<0)|(1<<1)|(1<<2);	// Enable the PWM on match 0,1&2 
	LPC_TMR16B0->MR0 = 0xFFFFFFFF;
	LPC_TMR16B0->MR1 = 0xFFFFFFFF;
	LPC_TMR16B0->MR2 = 0xFFFFFFFF;
	LPC_TMR16B0->MR3 = PWM_PERIOD;				
	LPC_TMR16B0->MCR = (1<<10);					// Reset on MR3 
	LPC_TMR16B0->CCR = 0; 						// Timer mode
	LPC_TMR16B0->TCR = (1<<1);					// reset counter and prescaler
	LPC_TMR16B0->TCR = (1<<0);					// enable timer and release reset
	
	/* CT16B1 : using irq */
	LPC_TMR16B1->EMR = (2<<6)|(2<<4)|(1<<1)|(1<<0);	// External match : set high on match 0,1 
	LPC_TMR16B1->PWMC = (1<<0)|(1<<1);			// Enable the PWM on match 0,1&2 
	LPC_TMR16B1->MR0 = 0xFFFFFFFF;
	LPC_TMR16B1->MR1 = 0xFFFFFFFF;
	LPC_TMR16B1->MR2 = 0xFFFFFFFF;
	LPC_TMR16B1->MR3 = PWM_PERIOD;				
	LPC_TMR16B1->MCR = (1<<6)|(1<<9)|(1<<10);	// Reset on MR3, interrupt on MR3 && MR2 
	LPC_TMR16B1->CCR = 0; 						// Timer mode
	LPC_TMR16B1->TCR = (1<<1);					// reset counter and prescaler
	LPC_TMR16B1->TCR = (1<<0);					// enable timer and release reset
	
	/* CT32B0 : using irq */
	LPC_TMR32B0->EMR = (2<<10)|(2<<8)|(1<<3)|(1<<2);	// External match : set high on match 2,3
	LPC_TMR32B0->PWMC = (1<<2)|(1<<3);			// Enable the PWM on match 2&3 
	LPC_TMR32B0->MR0 = PWM_PERIOD;
	LPC_TMR32B0->MR1 = 0xFFFFFFFF;
	LPC_TMR32B0->MR2 = 0xFFFFFFFF;
	LPC_TMR32B0->MR3 = 0xFFFFFFFF;				
	LPC_TMR32B0->MCR = (1<<0)|(1<<1)|(1<<3);	// Reset on MR0, interrupt on MR0 && MR1 
	LPC_TMR32B0->CCR = 0; 						// Timer mode
	LPC_TMR32B0->TCR = (1<<1);					// reset counter and prescaler
	LPC_TMR32B0->TCR = (1<<0);					// enable timer and release reset

	/* CT32B1 */
	LPC_TMR32B1->EMR = (2<<8)|(2<<6)|(2<<4)|(1<<2)|(1<<1)|(1<<0);	// External match : set high on match 0,1,2 
	LPC_TMR32B1->PWMC = (1<<0)|(1<<1)|(1<<2);	// Enable the PWM on match 0,1&2 
	LPC_TMR32B1->MR0 = 0xFFFFFFFF;
	LPC_TMR32B1->MR1 = 0xFFFFFFFF;
	LPC_TMR32B1->MR2 = 0xFFFFFFFF;
	LPC_TMR32B1->MR3 = PWM_PERIOD;				
	LPC_TMR32B1->MCR = (1<<10);					// Reset on MR3 
	LPC_TMR32B1->CCR = 0; 						// Timer mode
	LPC_TMR32B1->TCR = (1<<1);					// reset counter and prescaler
	LPC_TMR32B1->TCR = (1<<0);					// enable timer and release reset
	
	NVIC_EnableIRQ(TIMER_16_1_IRQn);    // Enable CT16B1 Interrupt       
	NVIC_EnableIRQ(TIMER_32_0_IRQn);    // Enable CT32B0 Interrupt       
}

__irq void TIMER16_1_IRQHandler(void)
{
	if (LPC_TMR16B1->IR & (1<<3))	// Match 3 irq? : timer reset
	{
		// Clear pending interrupt
		LPC_TMR16B1->IR |=(1<<3);
		
		// Led G3 off (if not 100% on)
		if(led[6] != 1.0 )GPIOSetValue(1, 5, 0);
	}
	if (LPC_TMR16B1->IR & (1<<2))	// Match 2 irq? : G3 soft pwm
	{
		// Clear pending interrupt
		LPC_TMR16B1->IR |=(1<<2);
		
		// Led G3 on
		GPIOSetValue(1, 5, 1);
	} 
}

__irq void TIMER32_0_IRQHandler(void)
{
	if (LPC_TMR32B0->IR & (1<<0))	// Match 0 irq? : timer reset
	{
		// Clear pending interrupt
		LPC_TMR32B0->IR |=(1<<0);
		
		// Led R3 off (if not 100% on)
		if(led[2] != 1.0 )GPIOSetValue(2, 6, 0);
	}
	if (LPC_TMR32B0->IR & (1<<1))	// Match 1 irq? : G3 soft pwm
	{
		// Clear pending interrupt
		LPC_TMR32B0->IR |=(1<<1);
		
		// Led R3 on
		GPIOSetValue(2, 6, 1);
	} 
}

/*----------------------------------------------------------------------------
  Function that initializes ADC
 *----------------------------------------------------------------------------*/
void ADC_init (void) 
{
  /* configure PIN GPIO0.11 for AD0 */
  LPC_SYSCON->SYSAHBCLKCTRL |= ((1UL <<  6) |   /* enable clock for GPIO      */
                                (1UL << 16) );  /* enable clock for IOCON     */

  LPC_IOCON->PIO1_11 = (1<<0);         			/* P1.11 is AD7               */
  LPC_GPIO1->DIR &= ~(1UL << 11);               /* configure GPIO as input    */

  /* configure ADC */
  LPC_SYSCON->PDRUNCFG      &= ~(1UL <<  4);    /* Enable power to ADC block  */
  LPC_SYSCON->SYSAHBCLKCTRL |=  (1UL << 13);    /* Enable clock to ADC block  */

  LPC_ADC->CR          =  ( 1UL <<  7) |        /* select AD7 pin             */
                          (11UL <<  8) |        /* ADC clock is 50MHz/12 = 4.2MHz / 11 clocks = 378 kHz */
                          ( 1UL << 21);         /* enable ADC                 */ 

  LPC_ADC->INTEN       =  ( 1UL <<  8);         /* global enable interrupt    */

  NVIC_EnableIRQ(ADC_IRQn);                     /* enable ADC Interrupt       */
}
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

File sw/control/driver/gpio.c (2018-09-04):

/****************************************************************************
 *   $Id:: gpio.c 9372 2012-04-19 22:56:24Z nxp41306                        $
 *   Project: NXP LPC11xx GPIO example
 *
 *   Description:
 *     This file contains GPIO code example which include GPIO 
 *     initialization, GPIO interrupt handler, and related APIs for 
 *     GPIO access.
 *
 ****************************************************************************
* Software that is described herein is for illustrative purposes only
* which provides customers with programming information regarding the
* products. This software is supplied "AS IS" without any warranties.
* NXP Semiconductors assumes no responsibility or liability for the
* use of the software, conveys no license or title under any patent,
* copyright, or mask work right to the product. NXP Semiconductors
* reserves the right to make changes in the software without
* notification. NXP Semiconductors also make no representation or
* warranty that such application will be suitable for the specified
* use without further testing or modification.

* Permission to use, copy, modify, and distribute this software and its 
* documentation is hereby granted, under NXP Semiconductors' 
* relevant copyright in the software, without fee, provided that it 
* is used in conjunction with NXP Semiconductors microcontrollers.  This 
* copyright, permission, and disclaimer notice must appear in all copies of 
* this code.
****************************************************************************/
#include "LPC11xx.h"			/* LPC11xx Peripheral Registers */
#include "gpio.h"

volatile uint32_t gpio0_counter = 0;
volatile uint32_t gpio1_counter = 0;
volatile uint32_t gpio2_counter = 0;
volatile uint32_t gpio3_counter = 0;
volatile uint32_t p0_1_counter  = 0;
volatile uint32_t p1_1_counter  = 0;
volatile uint32_t p2_1_counter  = 0;
volatile uint32_t p3_1_counter  = 0;

/*****************************************************************************
** Function name:		PIOINT0_IRQHandler
**
** Descriptions:		Use one GPIO pin(port0 pin1) as interrupt source
**
** parameters:			None
** Returned value:		None
** 
*****************************************************************************/
void PIOINT0_IRQHandler(void)
{
  uint32_t regVal;

  gpio0_counter++;
  regVal = GPIOIntStatus( PORT0, 1 );
  if ( regVal )
  {
	p0_1_counter++;
	GPIOIntClear( PORT0, 1 );
  }		
  return;
}

/*****************************************************************************
** Function name:		PIOINT1_IRQHandler
**
** Descriptions:		Use one GPIO pin(port1 pin1) as interrupt source
**
** parameters:			None
** Returned value:		None
** 
*****************************************************************************/
void PIOINT1_IRQHandler(void)
{
  uint32_t regVal;

  gpio1_counter++;
  regVal = GPIOIntStatus( PORT1, 1 );
  if ( regVal )
  {
	p1_1_counter++;
	GPIOIntClear( PORT1, 1 );
  }		
  return;
}

/*****************************************************************************
** Function name:		PIOINT2_IRQHandler
**
** Descriptions:		Use one GPIO pin(port2 pin1) as interrupt source
**
** parameters:			None
** Returned value:		None
** 
*****************************************************************************/
void PIOINT2_IRQHandler(void)
{
  uint32_t regVal;

  gpio2_counter++;
  regVal = GPIOIntStatus( PORT2, 1 );
  if ( regVal )
  {
	p2_1_counter++;
	GPIOIntClear( PORT2, 1 );
  }		
  return;
}

/*****************************************************************************
** Function name:		PIOINT3_IRQHandler
**
** Descriptions:		Use one GPIO pin(port3 pin1) as interrupt source
**
** parameters:			None
** Returned value:		None
** 
*****************************************************************************/
void PIOINT3_IRQHandler(void)
{
  uint32_t regVal;

  gpio3_counter++;
  regVal = GPIOIntStatus( PORT3, 1 );
  if ( regVal )
  {
	p3_1_counter++;
	GPIOIntClear( PORT3, 1 );
  }		
  return;
}

/*****************************************************************************
** Function name:		GPIOInit
**
** Descriptions:		Initialize GPIO, install the
**						GPIO interrupt handler
**
** parameters:			None
** Returned value:		true or false, return false if the VIC table
**						is full and GPIO interrupt handler can be
**						installed.
** 
*****************************************************************************/
void GPIOInit( void )
{
  /* Enable AHB clock to the GPIO domain. */
  LPC_SYSCON->SYSAHBCLKCTRL |= (1<<6);
  LPC_IOCON->R_PIO1_1  &= ~0x07;
  LPC_IOCON->R_PIO1_1  |= 0x01;

  /* Set up NVIC when I/O pins are configured as external interrupts. */
  NVIC_EnableIRQ(EINT0_IRQn);
  NVIC_EnableIRQ(EINT1_IRQn);
  NVIC_EnableIRQ(EINT2_IRQn);
  NVIC_EnableIRQ(EINT3_IRQn);
  return;
}
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

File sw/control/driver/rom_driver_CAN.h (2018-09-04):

/****************************************************************************
 *   $Id:: rom_driver_CAN.h 41 2012-02-12 16:03:02Z sander                  $
 *   Project: NXP LPC11xx CAN example
 *
 *   Description:
 *     This file is part of the CAN and CANopen on-chip driver examples.
 *
 ****************************************************************************
 * Software that is described herein is for illustrative purposes only
 * which provides customers with programming information regarding the
 * products. This software is supplied "AS IS" without any warranties.
 * NXP Semiconductors assumes no responsibility or liability for the
 * use of the software, conveys no license or title under any patent,
 * copyright, or mask work right to the product. NXP Semiconductors
 * reserves the right to make changes in the software without
 * notification. NXP Semiconductors also make no representation or
 * warranty that such application will be suitable for the specified
 * use without further testing or modification.
****************************************************************************/
#ifndef __ROM_DRIVER_CAN_H__
#define __ROM_DRIVER_CAN_H__

#include "LPC11xx.h"

// error status bits
#define CAN_ERROR_NONE  0x00000000UL
#define CAN_ERROR_PASS  0x00000001UL
#define CAN_ERROR_WARN  0x00000002UL
#define CAN_ERROR_BOFF  0x00000004UL
#define CAN_ERROR_STUF  0x00000008UL
#define CAN_ERROR_FORM  0x00000010UL
#define CAN_ERROR_ACK   0x00000020UL
#define CAN_ERROR_BIT1  0x00000040UL
#define CAN_ERROR_BIT0  0x00000080UL
#define CAN_ERROR_CRC   0x00000100UL

// control bits for CAN_MSG_OBJ.mode_id
#define CAN_MSGOBJ_STD  0x00000000UL   // CAN 2.0a 11-bit ID
#define CAN_MSGOBJ_EXT  0x20000000UL   // CAN 2.0b 29-bit ID
#define CAN_MSGOBJ_DAT  0x00000000UL   // data frame
#define CAN_MSGOBJ_RTR  0x40000000UL   // rtr frame

typedef struct _CAN_MSG_OBJ {
  uint32_t  mode_id;
  uint32_t  mask;
  uint8_t   data[8];
  uint8_t   dlc;
  uint8_t   msgobj;
}CAN_MSG_OBJ;

/**************************************************************************
SDO Abort Codes
**************************************************************************/
#define SDO_ABORT_TOGGLE          0x05030000UL  // Toggle bit not alternated
#define SDO_ABORT_SDOTIMEOUT      0x05040000UL  // SDO protocol timed out
#define SDO_ABORT_UNKNOWN_COMMAND 0x05040001UL  // Client/server command specifier not valid or unknown
#define SDO_ABORT_UNSUPPORTED     0x06010000UL  // Unsupported access to an object
#define SDO_ABORT_WRITEONLY       0x06010001UL  // Attempt to read a write only object
#define SDO_ABORT_READONLY        0x06010002UL  // Attempt to write a read only object
#define SDO_ABORT_NOT_EXISTS      0x06020000UL  // Object does not exist in the object dictionary
#define SDO_ABORT_PARAINCOMP      0x06040043UL  // General parameter incompatibility reason
#define SDO_ABORT_ACCINCOMP       0x06040047UL  // General internal incompatibility in the device
#define SDO_ABORT_TYPEMISMATCH    0x06070010UL  // Data type does not match, length of service parameter does not match
#define SDO_ABORT_UNKNOWNSUB      0x06090011UL  // Sub-index does not exist
#define SDO_ABORT_VALUE_RANGE     0x06090030UL  // Value range of parameter exceeded (only for write access)
#define SDO_ABORT_TRANSFER        0x08000020UL  // Data cannot be transferred or stored to the application
#define SDO_ABORT_LOCAL           0x08000021UL  // Data cannot be transferred or stored to the application because of local control
#define SDO_ABORT_DEVSTAT         0x08000022UL  // Data cannot be transferred or stored to the application because of the present device state

typedef struct _CAN_ODCONSTENTRY {
  uint16_t index;
  uint8_t  subindex;
  uint8_t  len;
  uint32_t val;
}CAN_ODCONSTENTRY;

// upper-nibble values for CAN_ODENTRY.entrytype_len
#define OD_NONE    0x00    // Object Dictionary entry doesn't exist
#define OD_EXP_RO  0x10    // Object Dictionary entry expedited, read-only
#define OD_EXP_WO  0x20    // Object Dictionary entry expedited, write-only
#define OD_EXP_RW  0x30    // Object Dictionary entry expedited, read-write
#define OD_SEG_RO  0x40    // Object Dictionary entry segmented, read-only
#define OD_SEG_WO  0x50    // Object Dictionary entry segmented, write-only
#define OD_SEG_RW  0x60    // Object Dictionary entry segmented, read-write

typedef struct _CAN_ODENTRY {
  uint16_t index;
  uint8_t  subindex;
  uint8_t  entrytype_len;
  uint8_t  *val;
}CAN_ODENTRY;

typedef struct _CAN_CANOPENCFG {
  uint8_t   node_id;
  uint8_t   msgobj_rx;
  uint8_t   msgobj_tx;
  uint8_t   isr_handled;
  uint32_t  od_const_num;
  CAN_ODCONSTENTRY *od_const_table;
  uint32_t  od_num;
  CAN_ODENTRY *od_table;
}CAN_CANOPENCFG;

// Return values for CANOPEN_sdo_req() callback
#define CAN_SDOREQ_NOTHANDLED     0  // process regularly, no impact
#define CAN_SDOREQ_HANDLED_SEND   1  // processed in callback, auto-send returned msg
#define CAN_SDOREQ_HANDLED_NOSEND 2  // processed in callback, don't send response

// Values for CANOPEN_sdo_seg_read/write() callback 'openclose' parameter
#define CAN_SDOSEG_SEGMENT        0  // segment read/write
#define CAN_SDOSEG_OPEN           1  // channel is opened
#define CAN_SDOSEG_CLOSE          2  // channel is closed
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

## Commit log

2018-09-04 Added hw sources
    [BOM Control v1.0.csv, BOM LineMixer v1.0.csv, BOM PSU v1.0.csv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]
2018-09-05 Added files for lasercutting
    [Back plate.DXF, Modwheel base.DXF, Modwheel mid.DXF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]

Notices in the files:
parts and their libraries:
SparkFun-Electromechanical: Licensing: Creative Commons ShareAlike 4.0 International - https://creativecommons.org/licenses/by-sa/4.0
